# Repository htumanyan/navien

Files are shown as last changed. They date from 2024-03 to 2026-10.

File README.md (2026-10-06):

# Navien ESPHome Integration 🚀🔥

Take control of your **Navien gas water heater** directly from Home
Assistant with this ESPHome module!

No more proprietary lock-ins - this project lets you seamlessly
integrate your Navien system into your smart home setup, giving you
automation superpowers like:

-   📱 Remote start/stop from Home Assistant
-   🔔 "Hot Button" entity that can be triggered from automation
-   ⚡ Climate control for setting the target temperature
-   🛠️ Easy to build, flash, and configure with YAML

## Screenshots 🖼️

Here are some examples of how the integration looks in Home Assistant:

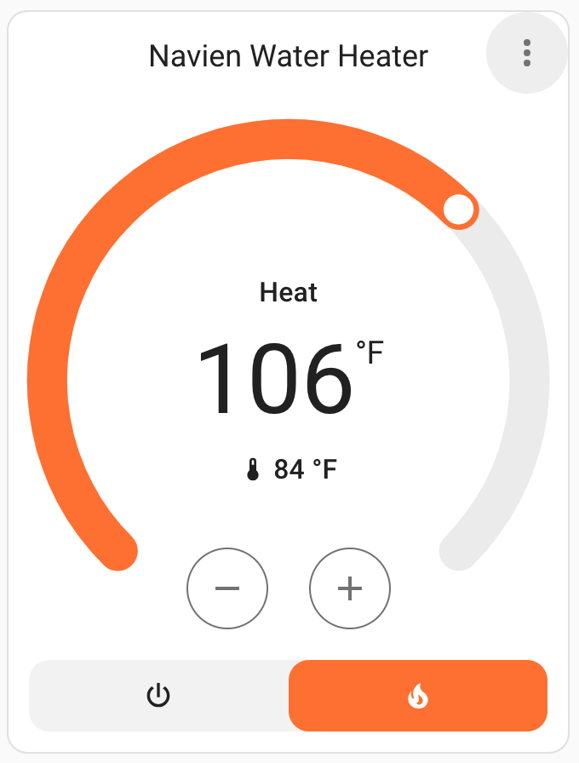
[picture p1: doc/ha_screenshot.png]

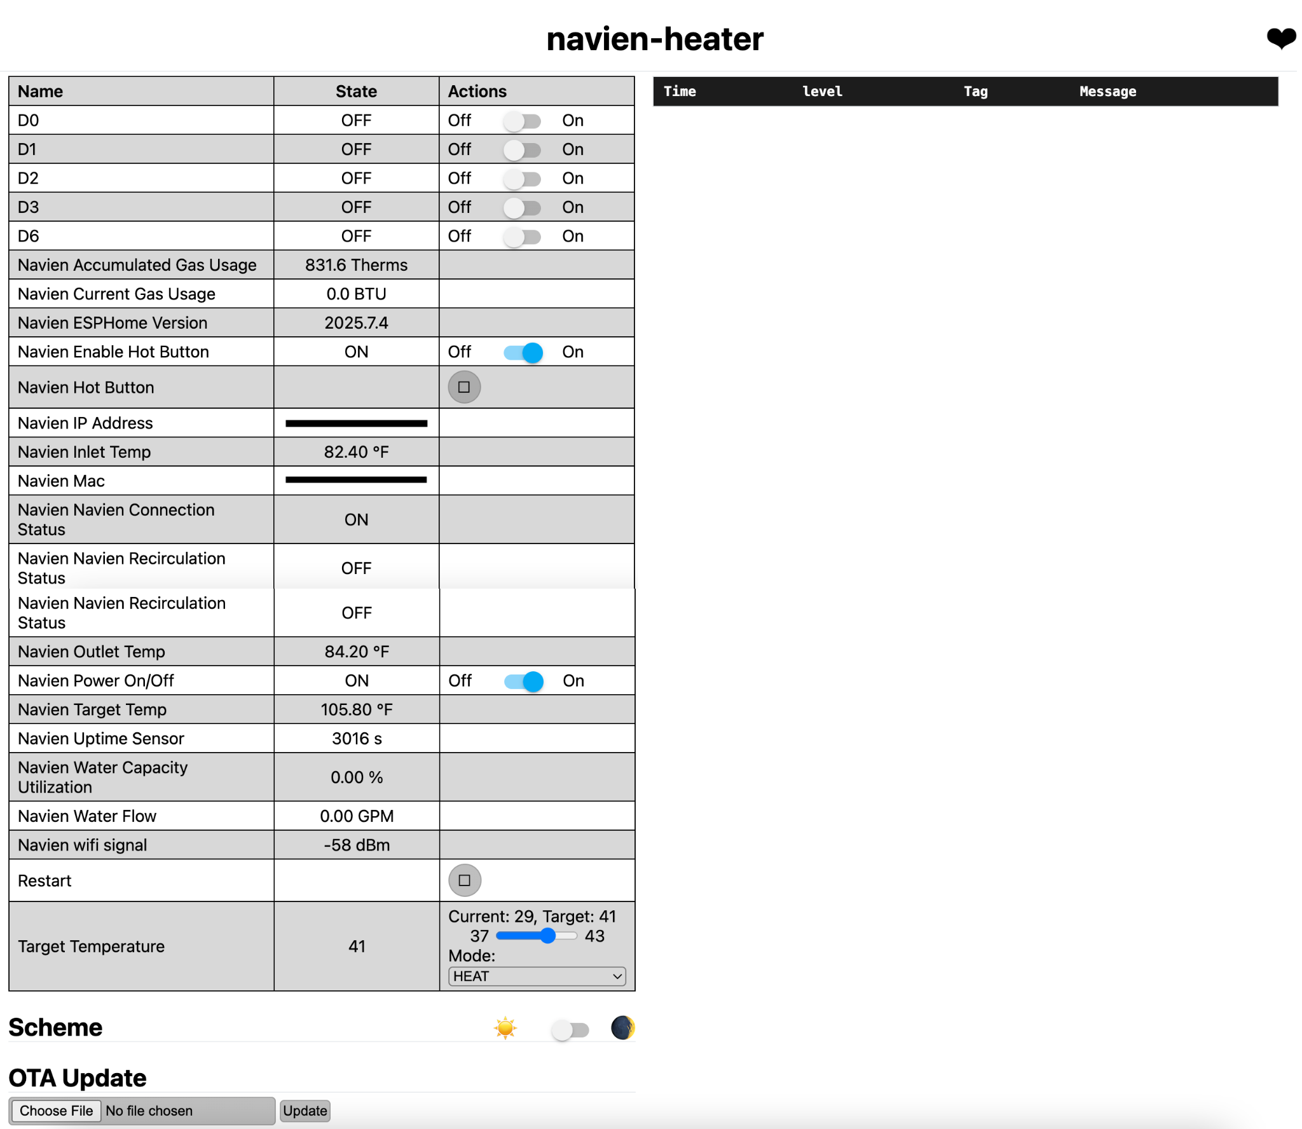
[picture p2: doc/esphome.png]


This project grew out of my work on reverse engineering the native Navien communication protocol to automate my Navien 240a, which it is tested with thoroughly (and works in my home every day). It also incorporates the knowledge from work done by amazing folks in Home Assistant community: [tsquared](https://github.com/tsquared96), [https://github.com/Suva](https://github.com/Suva), [evanjarrett](https://github.com/evanjarrett), David Carson, smurf12345 and many others who contributed in the [community thread](https://community.home-assistant.io/t/navien-esp32-navilink-interface/720567/118)

👉 GitHub Repo: [htumanyan/navien](https://github.com/htumanyan/navien)

------------------------------------------------------------------------

## Getting Started 🛠️

Follow these steps to build and run your own Navien ESPHome integration.

### 1. Clone the Repository

```
git clone https://github.com/htumanyan/navien.git 
cd navien
```

### 2. Install ESPHome

If you don't already have ESPHome installed:

```
pip install esphome
```

For detailed installation instructions, see the [ESPHome Getting Started
guide](https://esphome.io/guides/getting_started_command_line.html).

### 3. Choose Your Configuration

There are five ready-to-use YAML configurations in this repo:

-   **navien-d1-mini.yml** → If you use the D1 Mini board
-   **navien-wrd-hb.yml** → Version for D1 Mini with a hardwired hot button simulator
-   **navien-esphome-atom-lite-esp32.yml** → If you use esp32 Atom Lite board
-   **navien-esphome-lolin-c3-mini.yml** → If you use a LOLIN/WEMOS C3 Mini board
-   **navien-ht-device.yml** → This is for custom esp device that I've designed and plan to open source soon

For ESPHome Dashboard's **Import from URL** workflow, use the LOLIN/WEMOS
C3 Mini package at
`github://htumanyan/navien/esphome/packages/navien-esphome-lolin-c3-mini.yaml@main`.

### 5. Configure Wi-Fi

```
cp secrets.yaml.sample secrets.yaml
```
Edit secrets.yaml - change XXXX to your Wi-Fi network/password and AP SSID network/password in case if it fails to acquire Wi-Fi connection

### 6. Compile and Upload

Compile your firmware:

```
bash esphome compile navien-wrd-hb.yml 
```

**IMPORTANT: ensure that you are running the latest version of esphome, 2025.11.4 or later. Esphome introduced incompatible changes after the version 2025.7.4 that this repo was based off of. Hence it is critical to ensure the latest version of esphome is applied.**

Flash it to your ESP32:

```
bash esphome run navien-wrd-hb.yml
```

### 7. Hardware

#### [Hardware Build Guide — RS485 Adapter](./hardware-guide.md)

Complete guide covering the M5Stack AtomS3 Lite + Atomic RS485 Base build, connector pinouts, wiring, how to enable NaviLink in the Navien installer menu, and common mistakes.

#### [Navien-240 Connector Reference](./doc/240.md)

---

### 8. Importing the Scheduled Recirculation Automation Blueprint

If you have a unit, such as the NPE2 series, that supports scheduled recirculation (meaning it has recirculation modes named something like "Always", "Intelligent", "Weekly", etc), and setting your unit to one of those modes results in the "Navien Recirculation Mode" sensor in Home Assistant reporting "External Scheduled" or "Internal Scheduled", then you can likely use the automation blueprint for scheduling your unit's recirculation times. To do that:

First, you need to create a Schedule entity that will control when circulation is active:

1. In Home Assistant, go to "Settings", "Devices and Services"
2. Click "Add integration"
3. Find "Schedule (helper)" and select it
4. Give the schedule a name like "Navien Recirculation", and set up the schedule (or you can do that part later)
5. Click "Create"

Then, set up the automation:

1. In Home Assistant, go to "Settings", "Automations & scenes", then to the "Blueprints" tab.
2. Click "Import Blueprint" in the lower-right corner
3. Enter Blueprint address: `https://raw.githubusercontent.com/htumanyan/navien/refs/heads/main/navien_schedule_automation_blueprint.yaml`
4. Click "Preview", then "Import blueprint"
5. In the list of blueprints, "Navien Scheduled Recirculation" should now appear. Click it.
6. Fill in all the values per the directions (you might need to create some more helper entities depending on how you want to do things)
7. Click "Save" and give the new automation a name.

### 📖 User Manual for Custom Navien Controller

For detailed instructions on connecting, configuring, and using the custom Navien controller device, see the [User Manual](./doc/user_manual.md). This guide covers hardware setup, wiring, and usage tips specific to the custom controller.

------------------------------------------------------------------------

## [Protocol Details](./doc/README.md) 🔬

If you're interested in how this integration works under the hood, check
out the [doc](./doc/README.md) subfolder.
It contains the **reverse-engineered details of the Navien
protocol**---including message formats, field definitions, and notes
from packet captures.

This section is for developers and contributors who want to:
- Understand the low-level communication between the ESP32 and Navien
heater
- Contribute improvements to the protocol implementation
- Extend support for additional Navien models or features

If you just want to use the integration, you don't need to worry about
this --- but if you love digging into protocols, that's where the magic
happens.

------------------------------------------------------------------------

## Next Steps 🌟

-   Add your device to **Home Assistant** using ESPHome integration.
-   Create **automations and dashboards** to trigger hot water
    recirculation with a tap, schedule, or voice assistant.
-   Share your setup and feedback with the community!

------------------------------------------------------------------------

💡 This project is community-driven. Contributions, pull requests, and
feature ideas are always welcome!

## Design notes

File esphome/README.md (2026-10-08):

# ESPHome Module for Navien
This folder contains a working implementation of Navien tankless water heater protocols in a form of an ESPHome module.

## Supported capabilities
* Reading heater parameters - temperature values, water and gas usage etc.
* Sending commands to start/stop and hot button
* Setting the space-heating (supply water) setpoint on combi / boiler units (verified on NCB-H) - see below

## Space-heating setpoint (combi / boiler units)

`send_sh_set_temp_cmd(deg_c)` sets the SH supply setpoint. There is no dedicated
platform yet; a template number works, and showing the unit's *reported* value
(not the last value typed) makes a rejected command visible:

```yaml
number:
  - platform: template
    name: "SH Setpoint"
    unit_of_measurement: "°F"
    device_class: temperature
    min_value: 104      # NCB-H SH range; the unit clamps anything outside it
    max_value: 180
    step: 1
    mode: box
    update_interval: 2s
    lambda: |-
      if (!id(navien_main).has_data()) return NAN;
      return id(navien_main).get_sh_set_temp_c() * 9.0f / 5.0f + 32.0f;
    set_action:
      - lambda: |-
          id(navien_main).send_sh_set_temp_cmd((x - 32.0f) * 5.0f / 9.0f);
```

The unit works in 0.5 °C steps (0.9 °F), so values round: 158 °F lands as 158.9.

## Requirements

The build script requires Python 3.11+ and one of:
- [uv](https://docs.astral.sh/uv/) (recommended)
- esphome installed via pip

## Usage

### Interactive build script (recommended)

```bash
cd esphome
uv run python build.py
```

The script will:
1. Prompt for WiFi credentials on first run (saved to `secrets.yaml`)
2. Let you select a hardware configuration
3. Choose an action (compile, upload, run, logs)
4. Copy firmware to `../build/` on successful compile

Your choices are persisted, so subsequent runs use your previous selections as defaults.

### Available configurations

| Config | Hardware |
|---|---|
| navien.yml | D1 Mini (ESP8266) - main config |
| navien-d1-mini.yml | D1 Mini variant |
| navien-esphome-atom-lite-esp32.yml | ESP32 Atom Lite |
| navien-esphome-atoms3-lite-tail485-esp32.yml | M5Stack AtomS3-Lite + Tail485 |
| navien-esphome-waveshare-esp32s3-rs485can.yml | Waveshare ESP32-S3-RS485-CAN |
| navien-ht-device.yml | Custom HT device |
| navien-wrd-hb.yml | D1 Mini with hardwired hot button |

### Manual build

If you prefer to run esphome directly:

```bash
cd esphome
cp secrets.yaml.sample secrets.yaml
# Edit secrets.yaml with your WiFi credentials

esphome compile navien.yml
esphome run navien.yml
```

### Alternative installation methods

**Using pip:**
```bash
pip install esphome
esphome compile navien.yml
```

**Using Docker:**
```bash
docker run --rm -v "${PWD}":/config esphome/esphome compile navien.yml
```

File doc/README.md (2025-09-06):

# Navien Tankless Heather Protocol

This repository captures reverse engineered description of the low level details on communication between Navien tankless water heaters and the Navilink WiFi lite device.

## High Level Details

Navien supports several types of remote control devices. The older generation, such as NR-21DU and similar connect with two wires that are used to provide power to the remote device and also for the data exchange. Newer and more complex NaviLink devices (NaviLink and NaviLink Lite) connect over RS-485 connector. The documentation refers to power provided over separate pins/wires but my heater did not. I had to connect a separate 12V power supply to the NaviLink lite that was used to capture the traces, analyzed here.

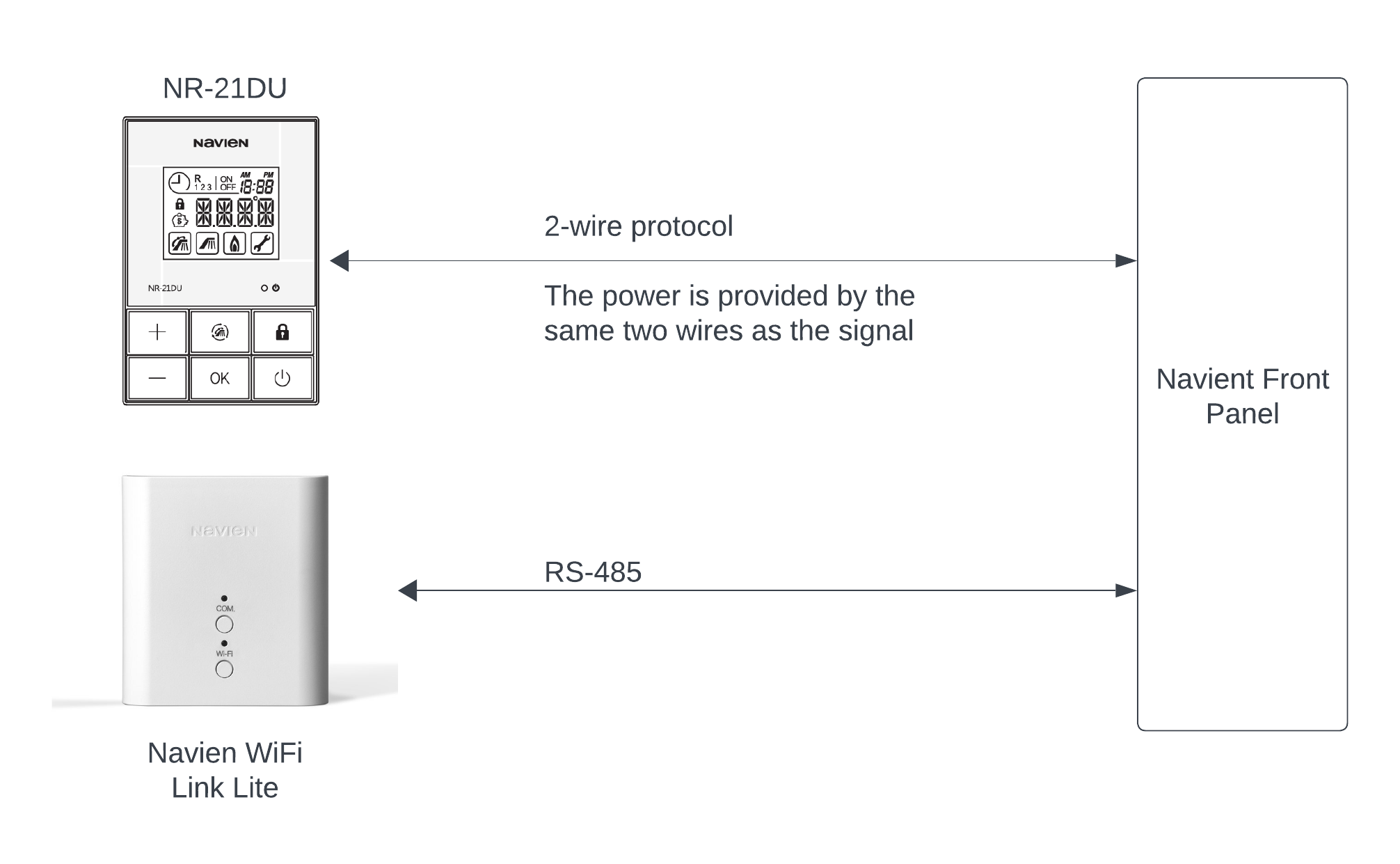
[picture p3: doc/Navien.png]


## Protocols
### [RS485 Connection](rs485.md)

 <!-- ### [2-Wire Connection](/doc/2-wire.md)-->

## Hardware/Firmware Exploration
## [Navien Wifi Link Lite](navien_wifi_debug.md)

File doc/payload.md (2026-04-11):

# Packet Types
The Navien protocol has two primary types of packets:

* Reporting Packets: These are sent from the heater to the consumer device. They contain various pieces of information, including heater status, temperature readings, flow rate (GPM), gas usage values, and other operational data.

* Control Packets: These are sent from the controller device to the heater. They are responsible for issuing commands, such as adjusting temperature settings, activating specific features, or controlling the heater's operation.

## Reporting Packets
Reporting packets are sent by Navien water heaters to indicate the status of the device. There are two kinds of reporting packets:

* Water - shows temperature values and the water flow
* Gas - temperatue values and gas usage.

Interestingly, the temperature values in gas and water packets, while often similar, are not always identical. It is likely that these values represent temperatures measured at closely located points within the system.

This distinction suggests that the gas and water temperature readings serve specific purposes, reflecting measurements taken at different but closely connected stages of the heating process.

Gas and water status segments are selected by destination/service routing in header byte 0x03 (`dst`), not by a standalone packet-kind byte.

For full source/destination/direction routing details, see [Protocol Data Flow](./protocol_data_flow.md).

```
+---------------------------------------------------
| F7 | Unknown Byte | Src | Dst | Direction | ....
+---------------------------------------------------

F7 - the fixed marker of a beginning of the packet

Unknown byte** - observed as 0x05, likely protocol/version marker

Src** - source node ID (for example `0x50` main status source, `0x0F` local controller)

Dst** - destination/service routing byte (`0x50` water status path, `0x0F` gas status path)

Direction** - parser treats `0x90` as status path and `0x10` as control path
```

### Sample Water Header

```
+---------------------------------------------------
| F7 | 0x05 | 0x50 | 0x50 | 0x90 | ....
+---------------------------------------------------
```

### Sample Gas Header

```
+---------------------------------------------------
| F7 | 0x05 | 0x50 | 0x0F | 0x90 | ....
+---------------------------------------------------
```

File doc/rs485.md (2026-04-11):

# The protocol over RS485 line

## Hardware Level

Analyzing the signal with an oscilloscope shown +12v and -12v pulses, which hinted that the signal may be regular RS485. That was confirmed later when connected Saleae logic analyzer. More detailed look into the timing of logic signals suggested the following parameters of the signal encoding:

* Speed 19200 bod
* 8 bit data frames
* 1 stop bit
* No parity

This was later confirmed in reverse engineering the firmware with Ghidra.

## Protocol

THe protocol is pretty simple in that there is no time coordination between requests and responses. Rather both sides, the remote control device and the heater just send packates over "their direction" of rs485. In other words, the communication is full duplex with two sides sending packets as they are ready.

## Packet Format

All packets, in both directions have a common overall format consisting of header, data part and a control sum.

Packets always start with a byte value 0xF7, which serves as a marker of starting the frame (also confirmed in reversed code).

| &nbsp; &nbsp; Header &nbsp; &nbsp; | &nbsp; &nbsp; &nbsp; &nbsp; &nbsp; &nbsp; &nbsp; &nbsp; Data &nbsp; &nbsp; &nbsp;  &nbsp; &nbsp;&nbsp;&nbsp; &nbsp; &nbsp; &nbsp; | &nbsp; &nbsp;  Checksum &nbsp; &nbsp;  |
|---|---|---|

#### Example

| | |
|---|---|
|Header|F7 05 50 50 90 22 | 
|Data | 42 00 00 25 49 5C 5B 53 00 00 00 00 00 00 88 C2 00 20 02 00 00 00 21 03 99 08 00 02 00 00 00 00 00 00 |
|Checksum| 87 |

### Header

Header fields are now better understood and mapped to current parser behavior.
These protocol flow learnings were refined during cascade troubleshooting and debug work with @matthewhadley.
For detailed flow semantics, see [Protocol Data Flow](./protocol_data_flow.md).

The table below shows known header field meanings:

| Offset | Purpose / Meaning |
|---|---|
| 0x00 | 0xF7 - fixed value. Marks the start of frame | 
| 0x01 | Observed to be always 0x05. However in the code there are references to 0x05 and 0x01 as well a a check for value to be in [1..9] range. |
| 0x02 | Source ID (`src`). Key values include: `0x01` (peer/panel handshake path), `0x0F` (local controller outbound sender), and `0x50..0x5F` (cascade unit range). Navien uses `0x50` and above for cascaded units (second, third, ... up to 15 units). |
| 0x03 | Destination ID (`dst`). Common observed values include `0x01`, `0x0F`, and `0x50`. Status parsing routes water/gas only for `0x50` and `0x0F`. |
| 0x04 | Direction byte. Known values used by parser gates are `0x10` and `0x90`. |
| 0x05 | Data length in bytes = packet length - header length - 1 byte for the checksum |

#### Example
| | |
|---|---|
|0xF7| Packet start marker |
|0x05| Unknown, always 0x05
|0x50| Source ID (`src`) |
|0x50| Destination ID (`dst`) |
|0x90| Direction |
|0x22| Length, 34 bytes
|42 00 00 25 14 5F 4C 4C 00 00 00 00 00 00 88 C2 00 20 02 00 00 00 21 03 9A 08 00 02 00 00 00 00 00 00| Data| 
|0xD8| Checksum

### [Protocol Data Flow](./protocol_data_flow.md)

### [Data Payload](/doc/payload.md)

### [Checksum Algorithm](/doc/checksum.md)

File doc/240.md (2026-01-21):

# Navien-240 hardware (240A / 240A2)

## Overview

This page is based on my research and experimentation, as well as contributions from the Home Assistant community, about the Navien-240 models (240A and 240A2) electronic internals.

## Front Display

### 240A

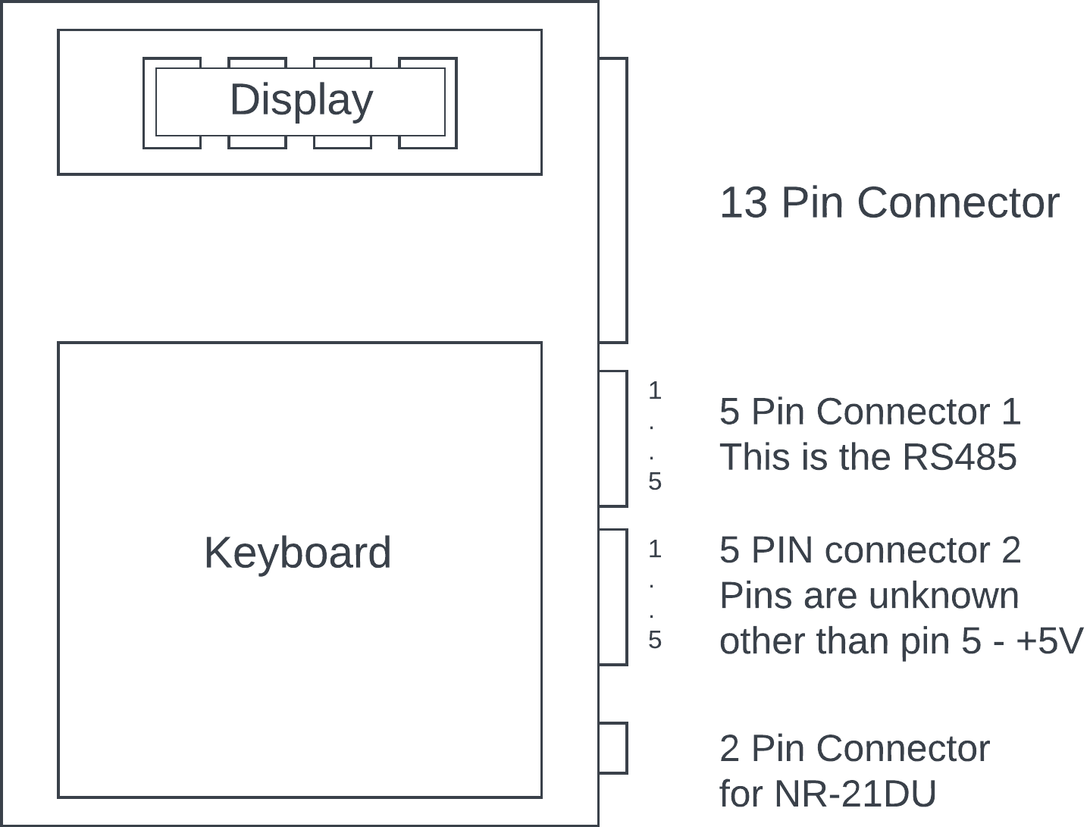
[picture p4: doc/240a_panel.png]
240A front panel


### 240A2

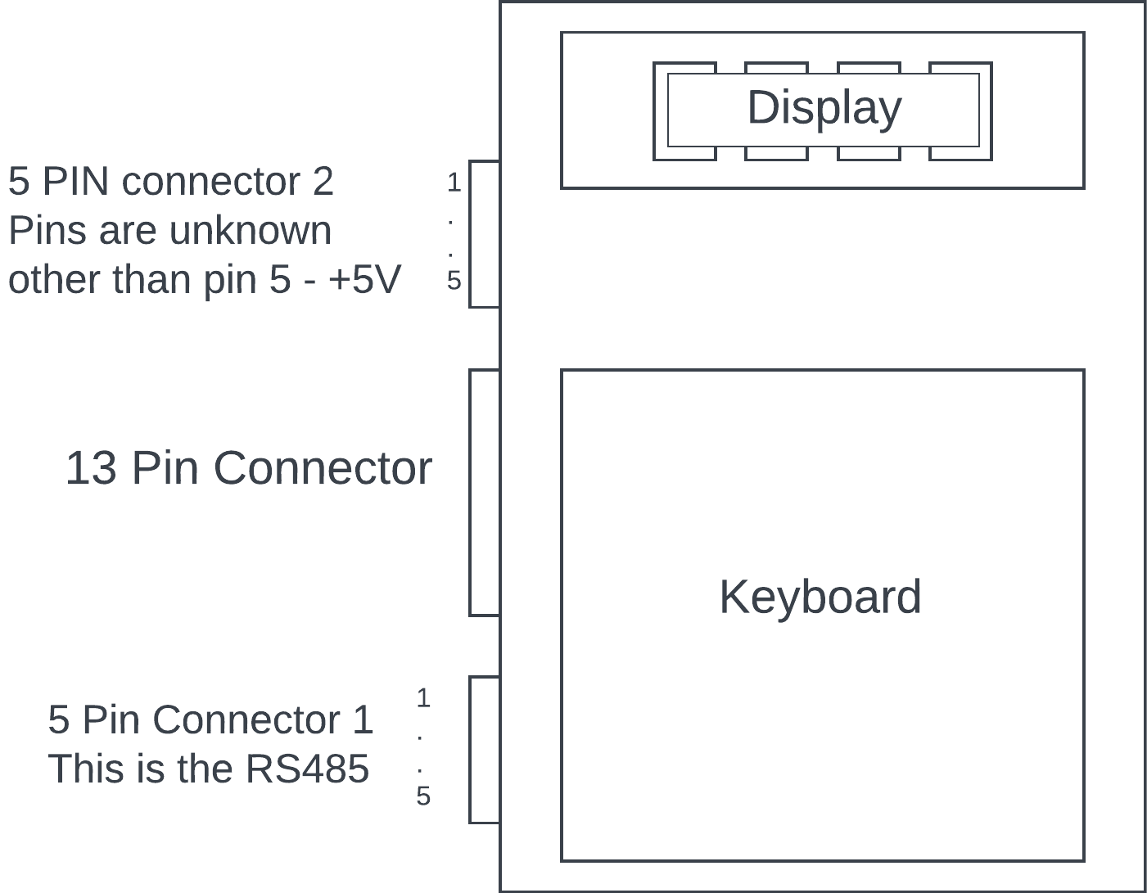
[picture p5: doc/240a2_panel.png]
240A2 front panel


## 5 Pin Connector 1 - RS-485 connection

| Pin | Purpose  |
|---|---|
| 1 | Unknown. Some reports indicate +13V in Navien-240A version |
| 2 | RS-485 B- |
| 3 | RS-485 A+ |
| 4 | Unknown |
| 5 | GND |

## 5 Pin Connector 2 - Largely Unknown, but has +5V

| Pin | Purpose  |
|---|---|
| 1 | Unknown |
| 2 | Unknown |
| 3 | Unknown |
| 4 | Unknown |
| 5 | +5V |

I've used the +5V to supply power to esp-8266, appears to have enough for it.

## 8 Pin RJ45 Connector (the one that comes with a NaviLink Lite)

If you want to use the cable that comes with the NaviLink Lite to connect via an RJ45 breakout board, here's the mapping to the 5 Pin connector 1:

| RJ45 Pin | Equiv. on connector 1 | Purpose |
|---|---|---|
| 1, 2 | 1 | +13V? |
| 4 | 3 | RS-485 A+ |
| 5 | 2 | RS-485 B- |
| 7, 8 | 5 | GND |

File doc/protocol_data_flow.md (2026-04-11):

# Navien Protocol Data Flow (RS-485)

This document summarizes observed and inferred data-flow rules for Navien packet headers.

## Header Field Semantics

### Source (`src`)

| Field | Value | Role / Semantics | Where It Is Used |
|---|---:|---|---|
| `src` | `0x01` | Peer/panel endpoint used by observed handshake/control-init traffic | Header comments and observed traffic |
| `src` | `0x0F` | Local gateway/controller ID (outbound sender) | Outbound builders set `src=0x0F` |
| `src` | `0x50` | Primary boiler telemetry source | Main parser status path, CRC seed `0x4B` branch |
| `src` | `0x50..0x5F` | Cascade unit source range (`0x50` base + unit index) | `Navien::on_water/on_gas` filter uses `PACKET_SRC_STATUS + src_`; Navien uses `0x50` and above for cascaded units (second, third, ... up to 15 units) |

### Destination (`dst`)

| Field | Value | Role / Semantics | Where It Is Used |
|---|---:|---|---|
| `dst` | `0x01` | Handshake target peer | Handshake builder sets `dst=0x01` |
| `dst` | `0x0F` | Local gateway/controller destination | Parser accepts for status import |
| `dst` | `0x50` | Main boiler destination path | Parser accepts for status import |
| `dst` | other values | Not imported into water/gas status callbacks | `parse_status_packet()` switches only on `0x50`/`0x0F` |

## Related Fields

| Related Field | Value | Semantics |
|---|---:|---|
| `direction` | `0x10` | Control packet path |
| `direction` | `0x90` | Status packet path |
| parser gate | `direction == 0x90` | Required for status packet parsing |
| status apply gate | `src == 0x50 + src_` | Required per-instance for water/gas state apply |

## Observed / Inferred Flow Patterns

| Src | Dst | Direction | Meaning | Status |
|---:|---:|---:|---|---|
| `0x0F` | `0x01` | `0x10` | Local gateway sends handshake/control-init packet to peer/panel endpoint | Observed |
| `0x01` | `0x0F` (likely) | `0x10` | Peer/panel-origin packet path | Inferred from comments and observed traffic |
| `0x0F` | `0x50` | `0x10` | Local gateway sends control requests toward main boiler node | Observed (command templates/builders) |
| `0x50` | `0x0F` | `0x10` or `0x90` | Main boiler telemetry/status accepted by parser for local import | Observed |
| `0x50` | `0x50` | `0x10` or `0x90` | Main-node loop/forwarded status path still accepted by parser | Observed |
| `0x50..0x5F` | `0x50` or `0x0F` | `0x90` | Cascade unit source range; per-instance apply uses `src-0x50` mapping | Inferred from instance filtering |

## Validation Rules

| Validation Rule | Semantics |
|---|---|
| `direction == 0x90` | Status CRC/parse path |
| `direction == 0x10 and src == 0x0F` | Control CRC/parse path |
| `direction == 0x90 and src == 0x50` | Status CRC uses seed `0x4B` |
| `direction == 0x90 and src != 0x50` | Status CRC uses seed `0x62` |
| `direction == 0x90 and dst in {0x50, 0x0F}` | Status segment routed to water/gas callbacks |
| `src == 0x50 + src_` (in Navien instance) | Water/gas state applied for matching unit only |

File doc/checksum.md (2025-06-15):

#  Checksum Algorithm

## Overview

The checksum algorithm initially appeared to be similar to CRC. After trying all known CRC values and implementations and failing to find a match to observed network traces I've pivoted to the hard way of reversing the assembly code and coding the algorithm in C/C++ based on inferred knowledge.

## Data Input
Notice that the checksum is generated across the whole packet, which includes the header and the data payload. Essentially, the validation code removes the very last byte that carries the checksum, computes the checksum on the remaining buffer and then compares the computation result to the removed byte. Similarly, the sender computes the checksum over the whole message that includes the header and data and then appends the computed checksum byte at the end.

## Seed Values

Just like CRC, the Navien checksum protocol employs a seed value. There are two known seed values that are selected in the code based on the value at offset 2 in the header (likely the protocol version). If the version value is 0x50 the seed is 0x4b. Otherwise it is 0x62. Notice that I never observed the 0x4b value in real world traces, so for all practical purposes the value needs to be 0x4b

## Algorithm

```
byte likely_crc_calc(const byte * buffer,uint len,ushort seed){
  ushort result;

  if (len < 2) {
    result = 0x00;
  }
  else {
    result = 0xff;

    for (uint i = 0; i < len; i++){
      result = result << 1;

      if (result > 0xff){
        result = (result & 0xff) ^ seed;
      }

      // this is important!!
      // the checksum is calculated
      // based on the lower byte, i.e.
      // only the lower byte is XOR-ed
      result = ((byte)result) ^ (ushort)buffer[i];
    }

  }

  return result;
}
```

### Working Code
There is a [working C/C++ code](/src/checksum.cpp) with test vectors derived from line captures. It can be compiled with GCC as follows:

```
gcc -g crc.cpp
```

It will produce the default a.out file in the current working directory that will run the tests if executed.

[Link to the working code with test cases](/src/checksum.cpp)

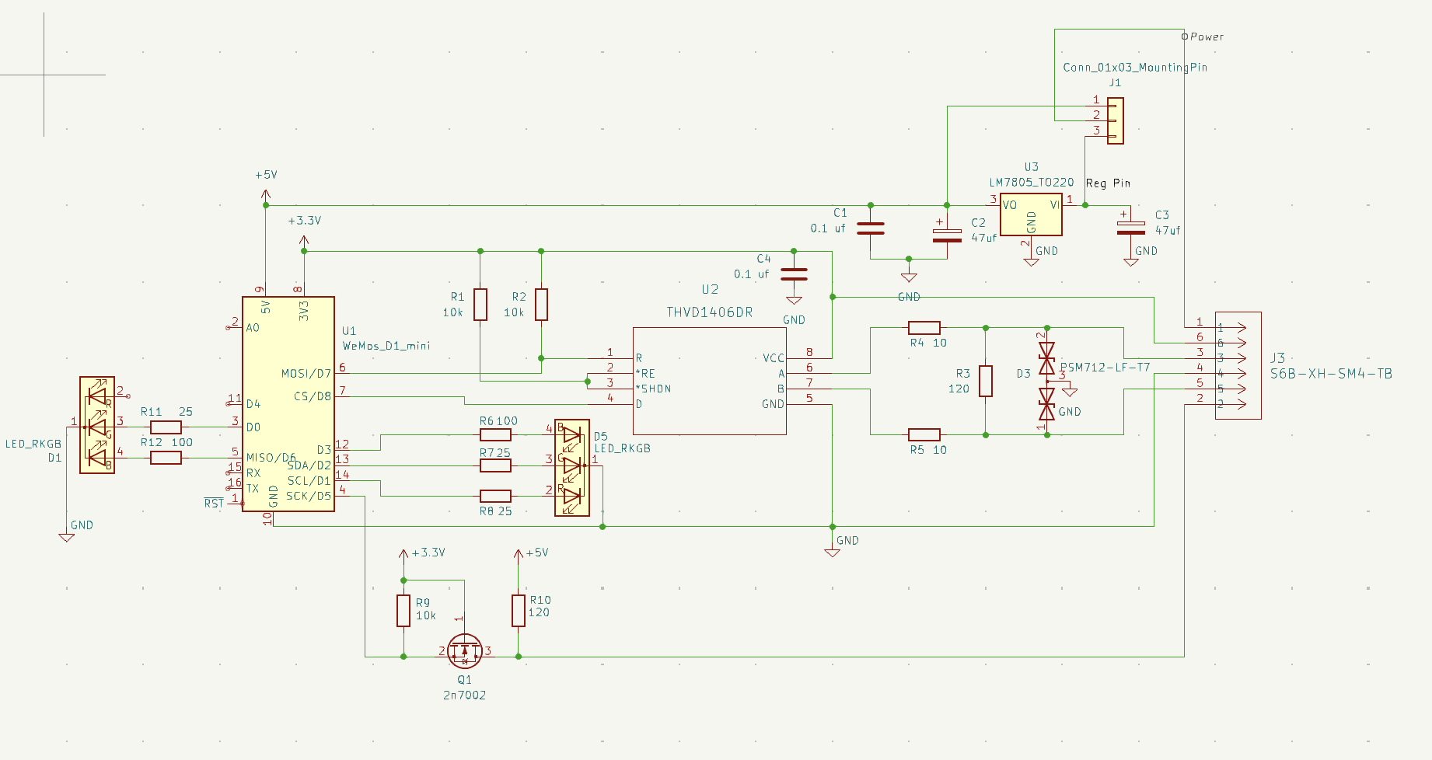
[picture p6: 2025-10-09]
hardware/Schematic.png

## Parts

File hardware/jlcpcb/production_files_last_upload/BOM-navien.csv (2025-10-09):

Comment | Designator | Footprint | LCSC | Quantity
100 | R12,R6 | R_0805_2012Metric_Pad1.20x1.40mm_HandSolder | C17408 | 2
10k | R1,R2,R9 | R_0805_2012Metric_Pad1.20x1.40mm_HandSolder | C17414 | 3
10 | R4,R5 | R_0805_2012Metric_Pad1.20x1.40mm_HandSolder | C17415 | 2
120 | R10,R3 | R_0805_2012Metric_Pad1.20x1.40mm_HandSolder | C17437 | 2
25 | R11,R7,R8 | R_0805_2012Metric_Pad1.20x1.40mm_HandSolder | C17634 | 3
S6B-XH-SM4-TB | J3 | CONN_S6B-XH-SM4-TB_JST | C191914 | 1
0.1 uf | C1,C4 | C_0805_2012Metric_Pad1.18x1.45mm_HandSolder | C28233 | 2
PSM712-LF-T7 | D3 | SOT-23 | C32677 | 1
THVD1406DR | U2 | SOIC_D0008A_TEX | C5215918 | 1
47uf | C2,C3 | C_0805_2012Metric_Pad1.18x1.45mm_HandSolder | C53134 | 2
LED_RKGB | D1,D5 | LED-ARRAY-SMD_4P-L1.6-W1.5-BL-FD-WITH-PIPE-2 | C601684 | 2
2n7002 | Q1 | SOT-23 | C8545 | 1

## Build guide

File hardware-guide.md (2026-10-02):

# Hardware Build Guide — RS485 Adapter for Navien

This guide summarizes everything you need to build a working RS485 adapter for your Navien tankless water heater, based on hundreds of posts from the [Home Assistant community thread](https://community.home-assistant.io/t/navien-esp32-navilink-interface/720567). It covers the Navien-side connector, four proven hardware options, wiring tables, and the common mistakes people make.

For full installation and parameter details, refer to the [Navien NPE-A/S Installation Manual](https://www.navieninc.com/downloads/npe-a-s-manuals-installation-manual-en).

---

## Before You Start: Enable NaviLink in the Installer Menu

**This is the single most common reason for a completely silent RS485 bus.** If the NaviLink communication mode is not enabled, your Navien unit sends no RS485 traffic at all, regardless of your hardware.

Access the installer menu as follows:

1. From the home screen, press and hold **Menu** and **↩ (back arrow)** simultaneously for 3 seconds. The service installer menu will appear.
2. Choose **option 1** to enter the installer menu and press **OK**.
3. Enter the default password **1234** using the up/down arrow buttons, then press **OK**.
4. Select **option 3 — Application Settings**, press **OK**.
5. Select **option 1 — NaviLink**, press **OK**.
6. Select **option 1 — NaviLink Connection**, press **OK**. Read the info screen and press **OK** again.
7. Move the cursor to **Enable** under NaviLink Connection and press **OK**.
8. Press **↩** repeatedly to exit all menu screens. The unit will reboot and purge the lines. Your ESP should then begin reporting data.

> **Note:** Units manufactured before approximately 2016 do not support NaviLink and cannot be used with this project.

---

## Physical Connector on the Navien Unit

The RS485 data connector is a **JST XH (2.54 mm pitch), 5-pin** connector located on the front display panel of the unit — the same port where the NaviLink Lite cable plugs in.

To access it:
1. Power off the Navien unit and unplug it from the wall.
2. Remove the front panel (typically two screws at the top, two at the bottom).
3. The RS485 connector is the 5-pin JST XH jack on the front display board.

| 240A front panel | 240A2 front panel |
|:---:|:---:|
| **Navien 240A** — RS485 connector is left of the back-arrow button | **Navien 240A2** — same connectors, mirrored position |

| 5-pin JST XH connector on the Navien 240A front panel | 5-pin JST XH connector on the Navien 240A2 front panel |
|:---:|:---:|
| 5-pin JST XH connector on the **Navien 240A** front panel | 5-pin JST XH connector on the **Navien 240A2** front panel (green PCB visible to the right of the display) |

### 5-Pin Connector 1 — RS485 Data

| Pin | Purpose |
|-----|---|
| 1 | ~+13 V (Navien 240A) |
| 2 | RS-485 B− |
| 3 | RS-485 A+ |
| 4 | Unknown / unused |
| 5 | GND |

### Mating Connector — JST XH vs XHB

The Navien uses a **JST XH** socket (2.54 mm pitch). You need a mating plug to connect your cable. There are two variants:

| | JST XH | JST XHB |
|---|---|---|
| Locking clip | No | Yes — a small plastic tab that clicks into place |
| Fits Navien socket | Yes | Yes |

Both variants are electrically identical and physically compatible with the Navien socket. The XHB locking clip is a convenience feature — the plain XH plug holds securely enough for a permanent install.

**Where to buy:**
- [Amazon — ACEIRMC 10-pair 5-pin JST **XH** connectors (male + female)](https://www.amazon.com/ACEIRMC-10Pairs-Connector-Connectors-Compatible/dp/B0D3LZHSTP)
- [AliExpress — JST **XHB** 5-pin connector set (locking)](https://www.aliexpress.us/item/3256806321864401.html)

| JST XH 5-pin connector | JST XHB 5-pin connector |
|:---:|:---:|
| JST XH — no locking clip | JST XHB — locking clip |

### Hot Button Requirement

The **hot button** feature (triggering instant hot water recirculation) requires two things: the Navien hot button kit must be installed on the main board, and the unit must be configured to **External HotButton** recirculation mode. If the mode is not set correctly, the Hot Button entity in Home Assistant will do nothing when pressed.

Whether the hardware is pre-installed depends on your model:

- **NPE-240A2** — the hot button kit comes **pre-installed**. No additional steps needed.
- **Other models (e.g. NPE-240A, NPE-210S)** — the hot button kit is **not included**. You must either purchase and install the official Navien hot button kit, or make the DIY bypass described below.

#### DIY Hot Button Bypass (13-pin JST XH connector)

The main board has an empty 13-pin JST XH socket where the hot button board plugs in. You can simulate the hot button kit by plugging a JST XHP-13 connector into that socket with two pins shorted together, and a wire on the +5 V pin that your ESP32 can pull low to trigger a hot button press.

> The 13-pin connector is **JST XH** (plain, no locking clip) — not XHB.

| 13-pin hot button bypass on the Navien main board |
|:---:|
| Annotated 13-pin connector. The embedded labels describe triggering a physical hot button press via a relay. The pin labelled "+5V" is a digital input that is pulled high — to trigger the hot button, pull it to 0 V. If you only want RS485-based virtual hot button (no relay), you need just 4 pins total: the two pins shorted together, and the 10 KΩ resistor |

#### Hot Button DIP Switches

The hot button controller board has a 4-position DIP switch (SW1) that controls its behavior:

| DIP SW | OFF | ON |
|---|-----|----|
| 1 | Enable the HotButton | Disable the HotButton |
| 2 | Enable the energy saver function | Disable the energy saver function |
| 3 | Reserved | Reserved |
| 4 | Reserved | Reserved |

| HotButton DIP switch diagram |
|:---:|
| SW1 DIP switch on the hot button controller board |

#### Temperature Sensor and SENSOR I Contacts

The hot button controller has a **SENSOR I** input for an optional recirculation return-line temperature sensor. By default, two metal contacts on SENSOR I are bridged by a metal plate — this is the no-sensor configuration and works without modification.

If you want to connect a temperature sensor, remove the metal plate before connecting the sensor. **Do not leave the plate installed while connecting a sensor, as this will short the sensor input.**

For most users: leave the metal plate in place and skip the temperature sensor entirely.

#### Fixture Distance (Parameter 16)

When no temperature sensor is connected (the default), the unit uses **Parameter 16** (fixture distance) to determine when to stop recirculating. The default value is **30 ft**. Adjust this parameter to match the approximate distance from the water heater to the furthest fixture if your setup differs significantly.

### RS485 Signal Levels

The Navien RS485 bus operates at standard RS485 differential levels (±12 V swing). Your RS485 transceiver IC handles the conversion to 3.3 V/5 V TTL logic for the ESP — **no separate level shifter is needed** on the RS485 data lines.

**UART settings for all configurations:**
- Baud rate: **19200**
- Data bits: 8
- Stop bits: 1
- Parity: None

---

## Hardware

The recommended build is the **M5Stack AtomS3 Lite + Atomic RS485 Base**. The base snaps onto the bottom of the AtomS3 Lite, accepts 12 V input directly from the Navien connector, and provides regulated power to the AtomS3 Lite. No breadboard or soldering required for the ESP side.

**Parts:**
- M5Stack AtomS3 Lite (ESP32-S3)
- [M5Stack Atomic RS485 Base](https://docs.m5stack.com/en/atom/Atomic%20RS485%20Base)
- JST XHP-5 (plain) or XHB (locking) 5-pin connector + wire, or pre-made cable

> **Termination resistor:** There is conflicting information about whether the Atomic RS485 Base includes an integrated 120 Ω termination resistor. The [latest schematics](https://docs.m5stack.com/en/atom/Atomic%20RS485%20Base) suggest it does; however, an [M5Stack example project](https://docs.m5stack.com/en/arduino/projects/atomic/atomic_rs485_232_base) calls for adding an external one. Other M5Stack RS485 products also ship with a loose through-hole resistor in the package — if yours does, use it across the A and B terminals. Do not add an external resistor if the base already has one integrated, as two resistors in parallel would drop the effective termination resistance below the correct 120 Ω. A unit ordered in June 2026 worked correctly without adding an external resistor.

| 120 Ω resistor across A and B terminals on the Atomic RS485 Base |
|:---:|
| 120 Ω resistor across the A and B terminals (highlighted) |

| M5Stack AtomS3 Lite + Atomic RS485 Base |
|:---:|
| Very nicely made custom cable with heat shrink, wire loom, and ferrules. Uses JST-XH connectors. |

**Wiring:**

| Atomic RS485 Base Terminal | Navien Connector 1 |
|---|---|
| B | Pin 2 (RS-485 B−) |
| A | Pin 3 (RS-485 A+) |
| 12V | Pin 1 (~+13 V) |
| GND | Pin 5 (GND) |

> Powering the base from the Navien's Pin 1 (+13 V) works reliably. The Atomic RS485 Base accepts 12–32 V input and provides regulated power to the AtomS3 Lite.

**UART pins (AtomS3 Lite):**

| Signal | GPIO |
|---|---|
| TX | GPIO2 |
| RX | GPIO1 |

**ESPHome YAML:** [`navien-esphome-atoms3-lite-rs485base-esp32.yaml`](esphome/packages/navien-esphome-atoms3-lite-rs485base-esp32.yaml)

### ESPHome Configuration

The easiest way to get started is to import the board config directly in the ESPHome dashboard using the **Import from URL** option with this URL:

```
github://htumanyan/esphome-navien/esphome/packages/navien-esphome-atoms3-lite-rs485base-esp32.yaml@main
```

This generates a minimal local config that pulls the full component definition from GitHub at build time. You only need to add your wifi credentials:

```yaml
substitutions:
  device_name: navien-abc123
  friendly_name: Navien abc123

packages:
  navien_board:
    url: https://github.com/htumanyan/esphome-navien
    ref: main
    files: [esphome/packages/navien-esphome-atoms3-lite-rs485base-esp32.yaml]
    refresh: 1d

esphome:
  name: ${device_name}
  name_add_mac_suffix: false
  friendly_name: ${friendly_name}

api:
  encryption:
    key: <your generated key>

wifi:
  ssid: !secret wifi_ssid
  password: !secret wifi_password
  ap:
    ssid: ${device_name} AP
    password: !secret ap_password
```

Updates to the shared component config are picked up automatically on the next compile — no need to re-import.

---

## Common Mistakes

1. **NaviLink not enabled in the installer menu.** The most common cause of a completely silent bus. Follow the steps at the top of this guide.

2. **RS485 A/B wires reversed.** If you get garbage data or silence, swap A and B.

3. **Termination resistor.** See the note in the Hardware section above — whether to add one depends on your specific unit.

4. **Wrong on/off byte values.** The NPE-240A and NPE-240A2 use different byte values for power state. Make sure you're using the right config file for your unit.

5. **ESPHome version.** Version 2025.7.4 introduced breaking changes. Use **2025.11.4 or later**.

---

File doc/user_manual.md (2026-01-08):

# Legal Notices

**READ THIS FIRST.** This custom controller (“Device”) is an aftermarket, third-party product that is **not manufactured, endorsed, certified, or supported by Navien**. Use of this Device may affect equipment operation, safety protections, warranty coverage, and regulatory compliance.

By installing, powering, or using the Device, you acknowledge and agree that:

- **Use is entirely at your own risk.**
- The Device is provided **“AS IS” and “AS AVAILABLE,”** without warranties of any kind, express or implied, including (without limitation) implied warranties of merchantability, fitness for a particular purpose, non-infringement, or that the Device will be error-free or uninterrupted.
- **No liability is assumed** by the developer, designer, seller, or distributor of the Device for any direct, indirect, incidental, special, consequential, exemplary, or punitive damages, including (without limitation) property damage, personal injury, loss of hot water, loss of heating, loss of data, loss of profits, or business interruption, arising out of or related to installation or use of the Device—even if advised of the possibility of such damages.
- You are solely responsible for **safe installation**, verifying compatibility, following all applicable **electrical codes**, and complying with all local laws and regulations.
- If you do not accept these terms, **do not install or use** the Device.

---

# User Manual — Navien Water Heater Controller (Custom Hardware)

## Table of Contents
1. Precautions  
2. Connections  
3. Powering the Unit  
4. LED Indicators  
5. Wi-Fi Connection  
6. Troubleshooting  

---

## Precautions

- **Never connect or disconnect the controller when the Navien unit is powered on.**  
  Always turn off the Navien unit and **unplug the power cord from the receptacle** before making or changing any connections.

- Before making any connections, ensure that the **power is turned off to all units** involved (Navien unit, any external power supply, and any nearby control equipment).

- Handle cables gently. Avoid bending, pinching, or pulling wires under tension.

---

## Connections

Your controller has **two connectors**:

### A) Micro-USB connector (side)
Used for:
- **Firmware upgrades**
- **Powering the controller**, if your Navien unit does not provide power (see **Powering the Unit**)

### B) 6-pin connector (Navien cable)
This connector receives the cable that connects the controller to the Navien unit. 

---

## Powering the Unit

### Option 1 (Universal): USB 5V power
The simplest way to power the unit is using a **standard 5V USB charger**, such as a typical phone power brick.

Steps:
1. Connect Micro-USB to the controller.
2. Plug the charger into AC power.
3. Confirm the controller powers on (see **LED Indicators**).

### Option 2: Power from the Navien unit (Navien 240 models)
**Your Navien 240 cable kit includes an additional small 5-pin connector with only one red wire.** This connector is used to draw **+5V power** from Navien 240 models (including **240A and 240A2**) and power the controller without an external USB charger.

Navien 240 models provide +5V power on the **second 5-pin jack on the front panel** (as shown in the photo). The controller can be powered from that jack using the single-red-wire connector.

To power the controller from a Navien 240 model:
1. Turn the Navien unit **OFF** and **unplug** it from the wall.
2. Locate the **second 5-pin jack** on the front panel.
3. Insert the **single-red-wire 5-pin connector** into that jack.  
   **Important:** this jack is **not keyed**. The connector must be inserted with the **red wire positioned at the bottom** (as shown in the photo).
4. Reconnect the main controller cable as usual.
5. Plug the Navien unit back in and power it on.

| Navien 240A front panel | Navien 240A2 front panel |
|:---:|:---:|
| **Navien 240A front panel** | **Navien 240A2 front panel** |

---

## Installation and Wiring

Steps:
1. Unpackage the controller and cable.
2. Plug the cable into the controller’s **6-pin jack**.
3. The connector is **keyed** and fits **only one orientation**.
4. **Do not force it.** If insertion feels wrong, remove it, flip the connector orientation, and try again.
5. Turn off the Navien unit - unplug the power cable from receptacle.
6. Remove the front panel of the Navien unit - it is usually attached by two screws at the top and two at the bottom.
7. Connect the main 5-pin connector (it has multiple wires going in it, as opposed to the second 5-pin connector that has just one red wire) to the 5-pin slot on the front display.
8. If your Navien unit is 240A and you don't have the Navien hot button kit installed, then insert the 13-pin connector into the empty 13-pin slot in the main board of the unit. This is to enable hot button functionality without the actual hot button device. If you have the Navien hot button device, then install it per Navien instructions and ignore this step.
9. Remove the front panel of the Navien unit - it is usually attached by two screws at the top and two at the bottom.
10. Plug in the power receptacle and turn on the Navien unit.

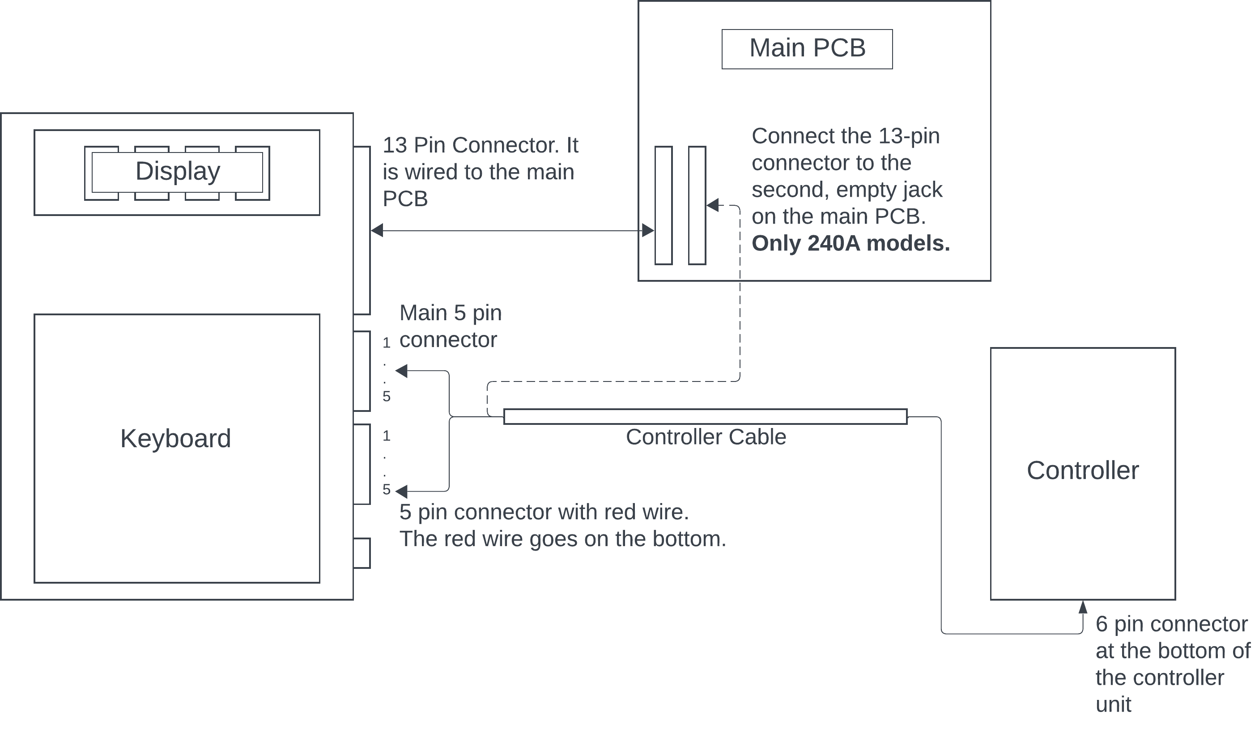
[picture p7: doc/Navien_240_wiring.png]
Navien 240A and 240A2 wiring diagram

**Navien 240A and 240A2 wiring diagram** 

## LED Indicators

There are **two LED indicators**:

### Left LED (Navien connectivity)
This LED can flash **green** or **red** and indicates connectivity to the Navien unit:
- **Green (flashing):** Connected; sending/receiving data  
- **Red (flashing):** Disconnected

✅ The left LED **must be green** for normal controller operation.

### Right LED (Wi-Fi status)
- **Solid Blue:** Connected to Wi-Fi  
- **Blinking Blue:** Attempting to connect to Wi-Fi  
- **Solid Purple:** Failed to connect to Wi-Fi and switched to **setup mode**

---

## Wi-Fi Connection

1. Power on the controller.  
   The **right LED (Wi-Fi)** will begin **blinking blue**.

2. Wait several minutes.  
   If the controller cannot connect to a previously saved Wi-Fi network, it will switch to setup mode and the LED will turn **solid purple**.

3. On your phone or laptop, connect to the Wi-Fi network:
   - **SSID:** `navien_wifi`  
   - **Password:** `navien_wifi`

4. After connecting, a browser popup should appear prompting you to:
   - Select your home Wi-Fi network
   - Enter the Wi-Fi password

5. After credentials are submitted:
   - The unit will **restart automatically**
   - The right LED should change to **solid blue** once connected to your Wi-Fi

---

## Wiring Diagram

## Troubleshooting

| Problem | Solution |
|---|---|
| No browser popup after connecting to `navien_wifi` | “Forget” the `navien_wifi` network on your phone/tablet/laptop and connect again. |
| Purple light does not switch to blue after network credentials are entered | Unplug the device, wait a few seconds, and plug it back in. |

Additional practical checks:
- Ensure your home Wi-Fi is **2.4 GHz** if your router separates 2.4/5 GHz networks (many embedded Wi-Fi devices require 2.4 GHz).
- Keep the controller close to the router during initial setup.

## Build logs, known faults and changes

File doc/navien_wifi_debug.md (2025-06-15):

# Navien Wifi Lite

## Hardware
Navien Wifi Lite has two processors onboard: ARM STM32F4 and quite exotic MIXCHIP ECM3280-E wifi module, ironically also ARM based according to the [datasheet](DS0145EN_EMC3280_v2.3.pdf).

STM32F4 is wired to MAX485 RS485 transciever on one side and connected to the MIXCHIP ECM3280-E wifi module on the other. STM32F4 has all the code and logic of parsing the line level protocol over RS485 connection to Navien decies. MIXCHIP ECM3280-E appears to be taking the Wifi connectivity, registration and also communication with Navien app through AWS cloud.

Notice that the communication to cloud servers is over TLS/SSL, which makes packet capture quite difficult. It is not clear whether client cert validation is implemented or potential MiM interception is possible to substitute keys and extract payloads.

## SWD Interface

Diagram 1 shows the outline of key components as seen from the bottom of the PCB board inside Wifi Lite. The most interesing are the pins in the top left corner, which are wired to the onboard SWD interface of STM32F4, creating the possibility of debugging the firmware onboard.

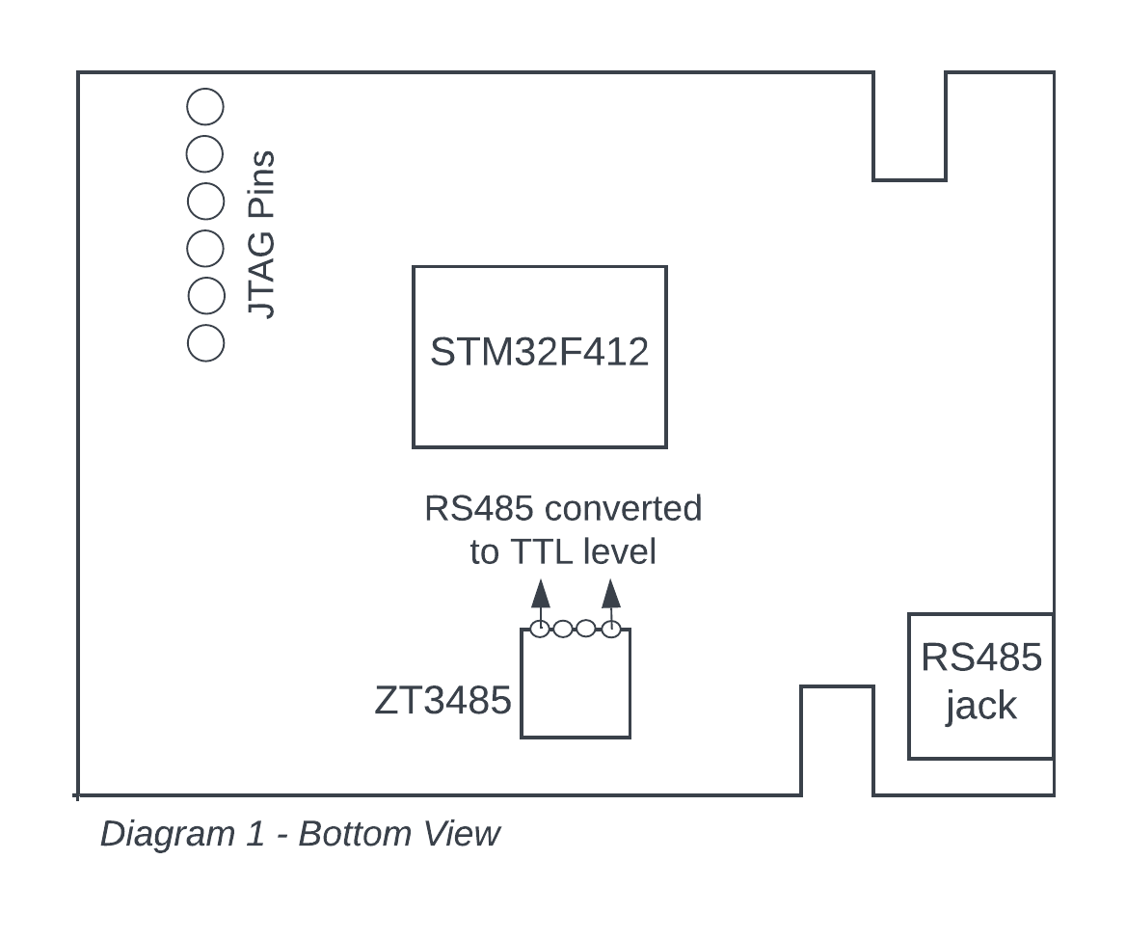
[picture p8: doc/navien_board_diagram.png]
Navien Board Diagram


STM32 devices can be debugged using either JTAG and SWD protocols. I did not find JTAG connectivity/port, but the SWD is present and confirmed to work.

The SWD setup for this board is as follows:

1. Install OpenOCD package
2. Connect ST-Link V2 Emulator Downloader Programmer to SWD pins as shown on the Diagram 2. For my experiments I've used a [cheap programmer from amazon](https://www.amazon.com/gp/product/B07SQV6VLZ) plugged into the USB port of the macbook.
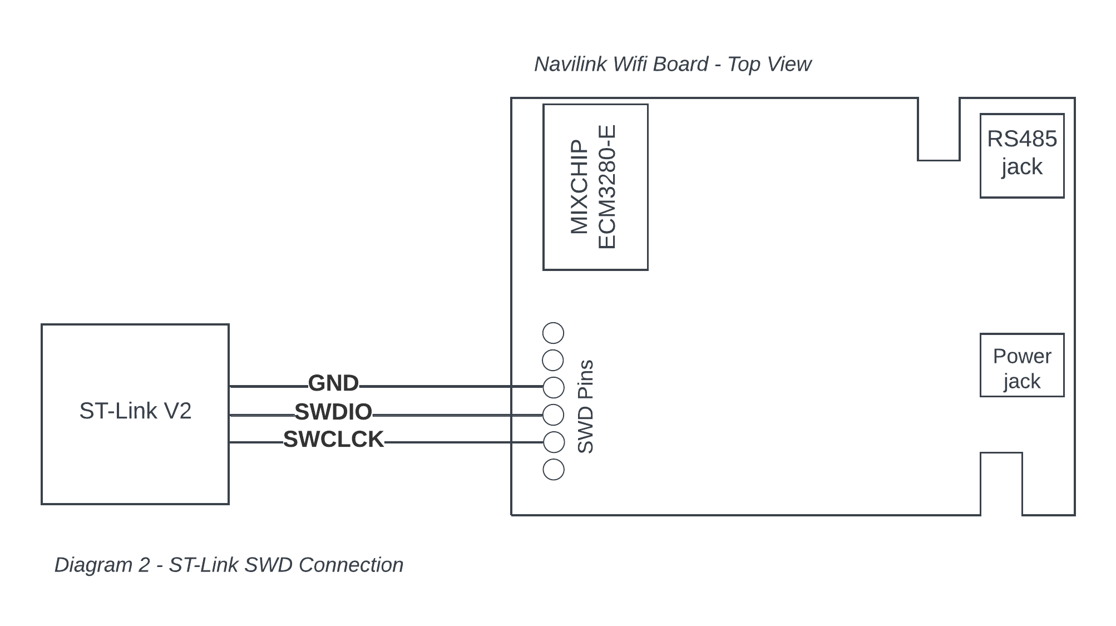
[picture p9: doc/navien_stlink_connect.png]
Navien ST-Link Connect


3. Start OpenOCD in the command shell with the following command (replace the path to openocd binary as necessary if it is not in your $PATH)
> openocd -f interface/stlink.cfg -f target/stm32f4x.cfg

4. Plug in the 12V power supply to the NaviLink

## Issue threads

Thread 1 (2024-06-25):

Any progress on the wire protocol / checksum?

itpeters, 2024-06-25:
Hi,

I stumbled across your work while trying to understand the Navien RS485 wire protocol. I have an ESP32 with TTL-RS485 converter connected to my Navien, and I've been watching some of the packets going back and forth.

From reading your work, it sounds like you believe the checksum to be CRC-8 of the entire packet (from the 0xF7 frame start through the end of the data), with the initial value dictated by the byte at offset 0x02 (either 0x62 or 0x4B) and (I'm assuming) polynomial 0x07.

I'm able to reproduce the first example you list:

```
>>> hex(crc.crc_poly(bytes.fromhex("F7 05 50 50 90 22 42 00 00 25 49 5C 5B 53 00 00 00 00 00 00 88 C2 00 20 02 00 00 00 21 03 99 08 00 02 00 00 00 00 00 00"), 8, poly=0x07, crc=0x62))
'0x87'
```

I'm not having the same success with your second example:

```
>>> hex(crc.crc_poly(bytes.fromhex("F7 05 50 50 90 22 42 00 00 25 14 5F 4C 4C 00 00 00 00 00 00 88 C2 00 20 02 00 00 00 21 03 9A 08 00 02 00 00 00 00 00 00"), 8, poly=0x07, crc=0x62))
'0xf3'
```

Your work showed this with a checksum of 0xD8.

I'm also not having any luck with the packets that I captured coming from my water heater. For example, I grabbed `F7 05 50 50 90 22 42 00 08 25 47 62 62 3E 00 00 00 00 00 00 08 9D 00 20 02 02 00 00 07 00 28 00 00 02 00 00 00 00 00 00 8A` but when I try to recreate the checksum I get something different:

```
>>> hex(crc.crc_poly(bytes.fromhex("F7 05 50 50 90 22 42 00 08 25 47 62 62 3E 00 00 00 00 00 00 08 9D 00 20 02 02 00 00 07 00 28 00 00 02 00 00 00 00 00 00"), 8, poly=0x07, crc=0x62))
'0x4d'
```

I was just curious if you see anything I'm doing wrong or misunderstanding, or if you have any more insights since you last put this up.

Thanks!

htumanyan, 2024-08-03:
Hello!
First of all, thank you so much for the attention and efforts! More of us try, sooner we get it reversed. I should admit I was a bit distracted for a few months, not making much progress. However, here is the reverse engineered CRC calculation code in case if it is helpful - this was on my list to document but never got a chance to - would very much appreciate any help.

undefined likely_crc_calc(byte *buffer,uint len,ushort seed)

{
  ushort uVar1;
  undefined *puVar2;
  byte *pbVar3;

  puVar2 = PTR_DAT_08031d7c;
  if ((int)len < 2) {
    *(undefined2 *)PTR_DAT_08031d7c = 0;
  }
  else {
    *(undefined2 *)PTR_DAT_08031d7c = 0xff;
    *(byte **)(puVar2 + 4) = buffer;
    while (pbVar3 = *(byte **)(puVar2 + 4), pbVar3 < buffer + ((len & 0xffff) - 1)) {
      uVar1 = *(short *)puVar2 << 1;
      *(ushort *)puVar2 = uVar1;
      if (0xff < uVar1) {
        *(ushort *)puVar2 = uVar1 & 0xff ^ seed;
      }
      *(byte **)(puVar2 + 8) = pbVar3;
      *(ushort *)puVar2 = *(ushort *)puVar2 ^ (ushort)*pbVar3;
      *(byte **)(puVar2 + 4) = pbVar3 + 1;
    }
  }
  return (char)*(undefined2 *)puVar2;
}

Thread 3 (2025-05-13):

2-wire protocol status

beren12, 2025-05-13:
Is there any chance you will work on the 2-wire protocol as well? I have a unit with that and would love to be able to change the set points via wifi instead of the remote, as well as have a timer to revert back to our preferred temp after a set time so others are less likely to get burned.

htumanyan, 2025-06-15:
Hello!
Thanks for asking and my apologies for taking forever to respond. I'd love to work on the two-wire protocol and it is in the plans. It is quite similar to the rs485 option as far as I can tell. I should admit, I don't know when I'll get to it though...

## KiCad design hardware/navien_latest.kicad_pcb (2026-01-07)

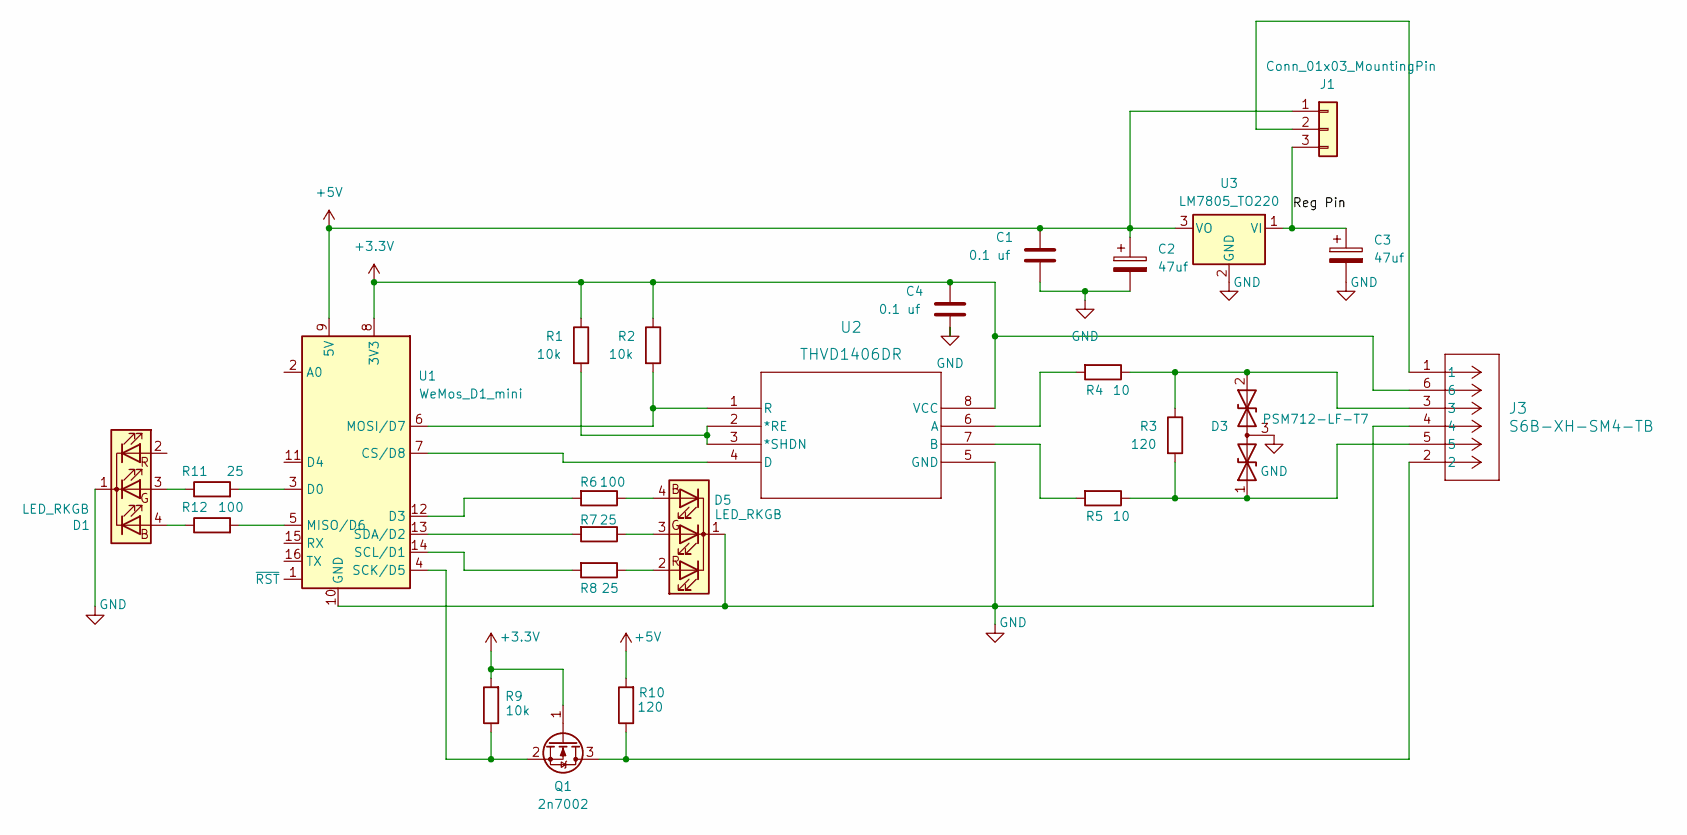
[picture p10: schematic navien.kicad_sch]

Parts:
C1, C4: 0.1 uf; C_0805_2012Metric_Pad1.18x1.45mm_HandSolder
C2, C3: 47uf; CP_EIA-3216-18_Kemet-A_Pad1.58x1.35mm_HandSolder
D1, D5: LED_RKGB; LED-ARRAY-SMD_4P-L1.6-W1.5-BL-FD
D3: PSM712-LF-T7; SOT-23
J1: Conn_01x03_MountingPin; PinHeader_1x03_P2.54mm_Vertical
J3: S6B-XH-SM4-TB; CONN_S6B-XH-SM4-TB_JST
Q1: 2n7002; SOT-23
R1, R2, R9: 10k; R_0805_2012Metric_Pad1.20x1.40mm_HandSolder
R3, R10: 120; R_0805_2012Metric_Pad1.20x1.40mm_HandSolder
R4, R5: 10; R_0805_2012Metric_Pad1.20x1.40mm_HandSolder
R6, R12: 100; R_0805_2012Metric_Pad1.20x1.40mm_HandSolder
R7, R8, R11: 25; R_0805_2012Metric_Pad1.20x1.40mm_HandSolder
U1: WeMos_D1_mini; WEMOS_D1_mini_light
U2: THVD1406DR; SOIC_D0008A_TEX
U3: LM7805_TO220; TO-220-3_Vertical

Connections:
+3.3V: C4.1, J3.6, Q1.1 (G), R1.1, R2.1, R9.2, U1.8 (3V3), U2.8 (VCC)
+5V: C1.1, C2.1, J1.1, R10.2, U1.9 (5V), U3.3 (VO)
/Reg Pin: C3.1, J1.3, U3.1 (VI)
GND: C1.2, C2.2, C3.2, C4.2, D1.1 (RA), D3.3 (common), D5.1 (Cathode), J3.4, U1.10 (GND), U2.5 (GND), U3.2 (GND)
unnamed: D1.3 (G), R11.1
unnamed: D1.4 (R), R12.1
unnamed: D3.1 (A1), J3.5, R3.2, R5.1
unnamed: D3.2 (A2), J3.3, R3.1, R4.1
unnamed: D5.2 (B), R8.1
unnamed: D5.3 (G), R7.1
unnamed: D5.4 (R), R6.1
unnamed: J1.2, J3.1
unnamed 12: R2.2, U1.6 (MOSI/D7), U2.1 (R); also elsewhere on the board
unnamed 13: U1.7 (CS/D8), U2.4 (D); also elsewhere on the board
unnamed: J3.2, Q1.3 (D), R10.1
unnamed: Q1.2 (S), R9.1, U1.4 (SCK/D5)
unnamed: R11.2, U1.3 (D0)
unnamed: R6.2, U1.12 (D3)
unnamed: R12.2, U1.5 (MISO/D6)
unnamed: R8.2, U1.14 (SCL/D1)
unnamed: R7.2, U1.13 (SDA/D2)
unnamed: R1.2, U2.2 (*RE), U2.3 (*SHDN)
unnamed: R4.2, U2.6 (A)
unnamed: R5.2, U2.7 (B)

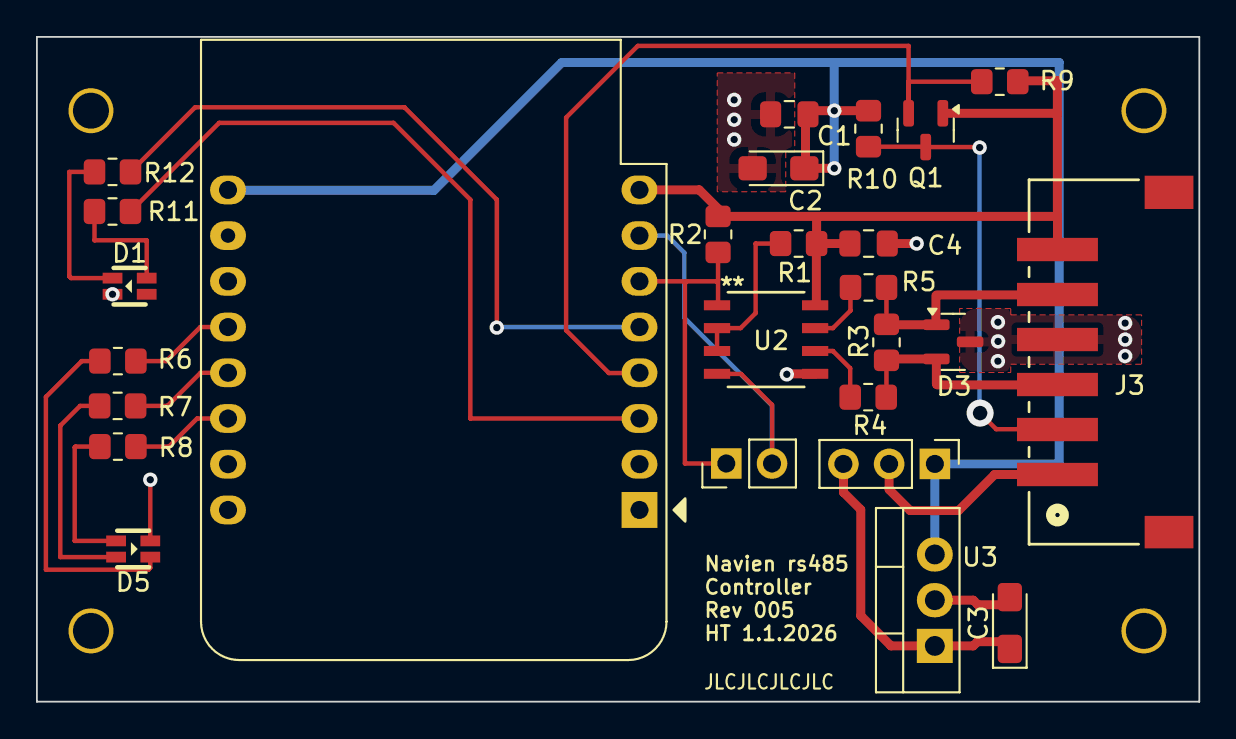
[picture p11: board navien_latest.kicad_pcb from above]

Board: 2 copper layers, 64.6 x 36.9 mm, 30 parts (0 on the bottom side), 24 nets.

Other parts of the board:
J2: Conn_01x02; PinHeader_1x02_P2.54mm_Vertical
REF1, REF2, REF3, REF4: MountingHole_2.2mm_M2

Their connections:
unnamed 12: J2.1; also elsewhere on the board
unnamed 13: J2.2; also elsewhere on the board

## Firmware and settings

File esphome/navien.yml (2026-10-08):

# Basic Config

substitutions:
  #   # https://esphome.io/guides/configuration-types.html#substitutions
  device_name: navien-heater # hostname & entity_id
  friendly_name: "Navien Gas Heater" # Displayed in HA frontend

esphome:
  # https://esphome.io/components/esphome
  name: ${device_name}

external_components:
  - source: 
      type: local
      path: components
    components: [navien]

esp8266: 
  board: d1_mini
  
wifi:
  ssid: !secret wifi_ssid
  password: !secret wifi_password
    
  # Enable fallback hotspot (captive portal) in case wifi connection fails
  ap:
    ssid: !secret ap_ssid
    password: !secret ap_password

captive_portal:

web_server:
  port: 80
  # https://esphome.io/components/web_server.html

logger:
#  level: VERBOSE #makes uart stream available in esphome logstream
  baud_rate: 0 #disable logging over uart

  hardware_uart: UART1 # redirect logs to UART1 GPIO2 to avoid conflicts
                       # with the MCU communication through the main hardware UART

  # https://esphome.io/components/logger
  level: INFO
  esp8266_store_log_strings_in_flash: false

api:

ota:
  platform: esphome


output:
  - platform: gpio
    pin: GPIO4  # D2 on esp8266
    id: uart_esp8266_d2

uart:
  tx_pin: GPIO15
  rx_pin: GPIO13
      
  baud_rate: 19200
  stop_bits: 1
  parity: none
  rx_buffer_size: 8192
  id: main_hw_uart


text_sensor:
  - platform: version
    name: $friendly_name ESPHome Version
    id: esphome_version
    hide_timestamp: True
  - platform: wifi_info
    ip_address:
      id: ip_address
      name: $friendly_name IP Address
    mac_address:
      name: $friendly_name Mac
      id: mac_address

sensor:
  - platform: uptime
    name: $friendly_name Uptime Sensor
  - platform: wifi_signal
    name: $friendly_name wifi signal
  - platform: navien
    name: $friendly_name Test sensor
    uart_id: main_hw_uart
    dhw_set_temperature:
      name: $friendly_name DHW Set Temp
      filters:
        - lambda: return x * (9.0/5.0) + 32.0;
      unit_of_measurement: "°F"
      device_class: temperature
      state_class: measurement
    inlet_temperature:
      name: $friendly_name Inlet Temp
      filters:
        - lambda: return x * (9.0/5.0) + 32.0;
      unit_of_measurement: "°F"
      device_class: temperature
      state_class: measurement
    outlet_temperature:
      name: $friendly_name Outlet Temp
      filters:
        - lambda: return x * (9.0/5.0) + 32.0;
      unit_of_measurement: "°F"
      device_class: temperature
      state_class: measurement
    sh_outlet_temperature:
      name: $friendly_name SH Outlet Temp
      filters:
        - lambda: return x * (9.0/5.0) + 32.0;
      unit_of_measurement: "°F"
      device_class: temperature
      state_class: measurement
    sh_return_temperature:
      name: $friendly_name SH Return Temp
      filters:
        - lambda: return x * (9.0/5.0) + 32.0;
      unit_of_measurement: "°F"
      device_class: temperature
      state_class: measurement
    water_flow:
      name: $friendly_name Water Flow
      filters:
        - lambda: return x / 3.785;
      unit_of_measurement: "gal/min"
      device_class: volume_flow_rate
      state_class: measurement
    water_utilization:  
      name: $friendly_name Water Capacity Utilization
      unit_of_measurement: "%"
    gas_total:
      name: $friendly_name Accumulated Gas Usage
      filters:
        - lambda: return x * 9131.0 / 25193.0 / 10.0;
      unit_of_measurement: "Therms"
      accuracy_decimals: 1
    gas_current:
      name: $friendly_name Current Gas Usage
      filters:
        - lambda: return x * 3.9680;
      unit_of_measurement: "BTU"
      accuracy_decimals: 1
    conn_status:
      name: $friendly_name Navien Connection Status
#    real_time: true           

binary_sensor:

switch:
  - platform: navien
    name: NavienOnOff


button:
  - platform: restart
    name: "Restart"
  - platform: navien
    name: NavienHotButton
    id: NavienHotButton


climate:
  - platform: navien
    id: navien_climate
    visual:
      min_temperature: 98F
      max_temperature: 110F
      temperature_step: '1°F'
    name: DHW Set Temperature

#output:
#  - platform: slow_pwm
##    pin: GPIO14
#    id: my_slow_pwm
#    period: 1s

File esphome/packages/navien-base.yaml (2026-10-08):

external_components:
  - source: github://htumanyan/esphome-navien@main
    components:
      - navien

time:
  - platform: homeassistant

web_server:
  version: 3

captive_portal:

api:

ota:
  - platform: esphome

logger:
  level: INFO

uart:
  id: main_hw_uart
  tx_pin: ${tx_pin}
  rx_pin: ${rx_pin}
  baud_rate: 19200
  stop_bits: 1
  parity: NONE
  rx_buffer_size: 8192

sensor:
  - platform: navien
    id: navien_main
    src: 0
    name: ${friendly_name} Metrics
    uart_id: main_hw_uart
    dhw_set_temperature:
      name: ${friendly_name} DHW Set Temp
      entity_category: diagnostic
      filters:
        - lambda: return x * (9.0/5.0) + 32.0;
      unit_of_measurement: °F
      device_class: temperature
      state_class: measurement
    inlet_temperature:
      name: ${friendly_name} Inlet Temp
      entity_category: diagnostic
      filters:
        - lambda: return x * (9.0/5.0) + 32.0;
      unit_of_measurement: °F
      device_class: temperature
      state_class: measurement
    outlet_temperature:
      name: ${friendly_name} Outlet Temp
      entity_category: diagnostic
      filters:
        - lambda: return x * (9.0/5.0) + 32.0;
      unit_of_measurement: °F
      device_class: temperature
      state_class: measurement
    water_flow:
      name: ${friendly_name} Water Flow
      entity_category: diagnostic
      filters:
        - lambda: return x / 3.785;
      unit_of_measurement: gal/min
      device_class: volume_flow_rate
      state_class: measurement
    water_utilization:
      name: ${friendly_name} Water Capacity Utilization
      entity_category: diagnostic
      unit_of_measurement: '%'
    heat_capacity:
      name: ${friendly_name} Heat Capacity
      entity_category: diagnostic
      unit_of_measurement: '%'
      accuracy_decimals: 1
    gas_total:
      id: gas_total_therms
      name: ${friendly_name} Accumulated Gas Usage
      entity_category: diagnostic
      filters:
        - lambda: return x * 9131.0 / 25193.0 / 10.0;
      unit_of_measurement: Therms
      accuracy_decimals: 1
    gas_current:
      id: gas_current_btu
      name: ${friendly_name} Current Gas Usage
      entity_category: diagnostic
      filters:
        - lambda: return x * 3.9680;
      unit_of_measurement: BTU
      accuracy_decimals: 1
    conn_status:
      name: ${friendly_name} Connection Status
      entity_category: diagnostic
    boiler_active:
      name: ${friendly_name} Boiler Active
      entity_category: diagnostic
    recirc_running:
      name: ${friendly_name} Recirculation Running
      entity_category: diagnostic
    recirc_mode:
      name: ${friendly_name} Recirculation Mode
      entity_category: diagnostic
    error_code:
      name: ${friendly_name} Error Code
      entity_category: diagnostic
    error_level:
      name: ${friendly_name} Error Level
      entity_category: diagnostic

  - platform: copy
    source_id: gas_total_therms
    name: ${friendly_name} Accumulated Gas Usage CCF
    entity_category: diagnostic
    unit_of_measurement: CCF
    device_class: gas
    state_class: total_increasing
    filters:
      - lambda: return x / 1.038;
    accuracy_decimals: 1
    disabled_by_default: true

  - platform: copy
    source_id: gas_current_btu
    name: ${friendly_name} Current Gas Usage kW
    entity_category: diagnostic
    unit_of_measurement: kW
    device_class: power
    state_class: measurement
    filters:
      - lambda: return x * 10.0 / 3412.0;
    accuracy_decimals: 1
    disabled_by_default: true

text_sensor:
  - platform: navien
    navien: navien_main
    name: ${friendly_name} Operating State
    entity_category: diagnostic
    operating_state: true
  - platform: navien
    navien: navien_main
    name: ${friendly_name} Heating Mode
    entity_category: diagnostic
    heating_mode: true

switch:
  - platform: navien
    navien: navien_main
    type: power
    name: ${friendly_name} Main Power
    entity_category: diagnostic
    id: main_power

button:
  - platform: navien
    name: ${friendly_name} Hot Button
  - platform: restart
    name: ${device_name} Restart
  - platform: safe_mode
    name: Flash Device (Safe Mode)
    icon: mdi:cellphone-arrow-down
    id: safe_mode_button

water_heater:
  - platform: navien
    navien: navien_main
    id: navien_water_heater
    visual:
      min_temperature: 98F
      max_temperature: 125F
      target_temperature_step: 1
    name: ${friendly_name}

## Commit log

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2024-08-27 Added the working code for checksum generation and validation along with test vectors derived from wire captures
2025-01-04 Added support for external secrets file Rename secrets.yaml sample into secrets.yaml and change XXXX to repsective ap name and password values
2025-02-03 Reworked the component structure for better alignment with esphome best practices Added Navien Switch for turning the heater on/off (tested to work with N240a)
    [navien.cpp, navien.yml]
2025-06-15 Fixed the compilation error due to incorrectly added button Added NavienOnOff switch for tracking the state of the device and also turning it on and off Added reporting of the water flow state
    [navien.cpp, navien.yml]
2025-06-15 Removed the unnecessray reference to custom button implementation Standard button does just fine
2025-06-24 Major refactoring to achieve greater flexibility: a. Created a new interface abstracting away the details of UART and modified the rest of the code to use that rather than the raw esphome UART API. b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
2025-06-24 Get 'upstream/refactor_separate_proto' compiling for me.
    Put the switch/button code under `USE_SWITCH`/`USE_BUTTON` in case the YAML config doesn't have a
    "switch:"/"button:" section. Move the pin write into the YAML config because my board doesn't have
    the pin.
    [navien.cpp, navien.yml, navien_link.cpp]
2025-06-25 Removed unnecessary parse_gas and parse_water that are now replaced with calls to on_gas and on_water in the implementation of NavienLinkVisitorI. Moved the code from parse_gas and parse_water to the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
    [navien_link.cpp]
2025-06-25 Fixed the incorrect position of water flow field and confirmed correct GPM reporting on the actual unit
2025-06-26 a. Fixed the bug in water flow calculation - was mistakenly treating the value as GPM while it was LPM b. Added the current gas consumption - it is reported in kkal/hr but shown as BTU in Navien. Imp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
    [navien.cpp, navien.yml]
2025-06-29 Added the water utilization (debugged to confirm proper functioning) Replaced the use of module-specific unit of m^3 with ESPHome standard
    [navien.cpp, navien.yml]
2025-06-29 Debugged and fixed the connection status reporting that was broken after refactoring. Moved the connection status into the Navien class from NavienLink. Previously I was hoping to move it to NavienLi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
    [navien.cpp, navien.yml, navien_link.cpp]
2025-06-29 Fixed the power on/off. Debugged and verified it is working Moved sensor updates into their own functions update_water_sensors and update_gas sensors so that we could call them either from the Pollin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
    [navien.cpp]
2025-06-30 Added connection status reporting Reversed, debugged and added support for "recirculation status" and measurement unit configuration
    [navien.cpp, navien.yml, navien_link.cpp]
2025-07-08 Added real time update of sensors upon receipt of packets if the configuration calls for real time updates (real_time: true)
2025-08-25 Split off the configuration into separate files to simplify building for various platforms.
    navien-wrd-hb.yml - for the option that has D5 pin connected to the hot button pin on Navien main board (hot button simulation)
    navien-ht-device.yml - for the custom device that was designed specifically for controlling Navien devices.
    navien-base.yml - base file re-used across all versions, contains common definitions
    navien.yml is still around but will be retired soon
2025-09-06 Updated the navien.yaml for the new structure of platofrm/board specification in the latest version of esphome
2025-09-06 Added Climate control that sets the target temperature and shows the target received from the Navien heater
2025-09-06 Fixed reading temp values from water packet (was missing proper conversion to temp units). Added support for modes - HEAT and OFF. Wired up the modes to the on/off state of the Navien unit. Turning o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
    [navien.cpp]
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2025-09-08 Removed unnecessary port manipulations. Added the thermostat (missed when thermostat support was developed)
    [navien.yml]
2025-09-19 Removed no longer necessary pull up pin directives that were inerfering with Atom boards
    [navien.yml]
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2025-09-26 Update CONF_GAS_TOTAL with device and state classes
    Allows sensor to be used in the energy dashboard
2025-10-09 Commented out the reverse engineered prototype to avoid compilation errors.
2025-10-09 Added the hardware KiCad project with schematic and PCB Added the PNG verison of schematic for easy preview
    [BOM-navien.csv, navien.kicad_pcb, navien.kicad_sch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]
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2025-11-29 Made LED lights come on/off based on Wi-Fi and RS-485 connection status
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2025-12-30 Temporary re-adddition of the soft rs485 button while figuring out a way to have both options
2026-01-07 doc: consolidate Navien 240 documentation (240A/240A2): add doc/240.md, update README, remove doc/240-a.md
    [BOM-navien.csv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]
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2026-01-11 Refactor(navien): extract enum-to-string helpers (op_state, heat_mode, device_type)
    [navien.kicad_pcb]
2026-01-12 Fixed the compilation error due to incorrect scoping of static functions in the previous commit. Removed unnecessary reference from atom-lite-esp32.yml Replaced static_cast with binary mask logic for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
    [navien-esphome-atom-lite-esp32.yml, navien.cpp]
2026-01-14 Refactor: Extract NavienLinkEsp as singleton for UART communication
    - Rename link_id to src across YAML and Python config files
    - Create NavienLinkEsp class to handle UART communication
    - NavienLinkEsp is now a Component with its own loop() for receiving data
    - NavienLinkEsp broadcasts received packets to all registered visitors
    - NavienBase now has NavienLinkEsp as a member via set_link() instead of inheritance
    - Singleton pattern in sensor.py ensures only one NavienLinkEsp instance
    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
2026-01-15 Phase 1 of refactoring to support multi-unit cascading setup. Modified the reception logic to decide on packet direction based on the direction field, modified the navien_link to pass along src id of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
2026-01-15 Restore text_sensor, switch components and YAML config from main branch. Added explicit navien IDs (navien_master, navien_slave) and parent references for multi-unit cascade support.
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2026-01-17 disabled parsing of control packets with the source other than 0xF as those are unknown at the moment (observed in cascade setup for 240A2 between navien units) and cause unnecessary errors.
    [navien_link.cpp]
2026-01-18 a. Thanks to collaboration with https://community.home-assistant.io/u/diffhome debugged and enabled support for Navien 240A2 in cascade configuration. b. Refactored sensor definitions- moved to a sep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
    [navien-esphome-atom-lite-esp32.yml]
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2026-01-19 Add support for scheduled recirculation
    This PR adds support for controlling when scheduled recirculation is active, which allows Home Assistant to replicate the weekly scheduling capability of the NaviLink app. It has been tested against 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
    It adds two new control packets `SCHEDULED_RECIRC_ON_CMD` and `SCHEDULED_RECIRC_OFF_CMD`. The first one tells the Navien unit that it can recirculate when it sees fit (and also triggers an immediate 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
2026-01-20 Fix Fahrenheit rounding issues
    [navien_link.cpp]
2026-01-21 Add support for m5Stack ATOM S3 Lite/Tail485
    Adds a configuration file for the ATOM S3 Lite with a Tail485, which uses a different pinout than the ATOM S3.
    Also adds info to `doc/240.md` about pin mapping between the 5-pin connector 1 and the NaviLink RJ45 cable.
2026-01-26 Use idf for atom-lite
    Also resolve an issue with the `/` character in the name of the power
    entity
    [navien-esphome-atom-lite-esp32.yml]
2026-01-26 Interactive build script
    - Add build.py for interactive firmware builds with persisted
    WiFi credentials and hardware selection
    - Add pyproject.toml for uv-based esphome dependency management
    - Copy firmware output to ./build/ for convenient access
    - Fix ESP32 Atom Lite config for ESPHome 2026.x:
    - Use ESP-IDF framework (now the default)
    - Replace fastled_clockless with esp32_rmt_led_strip
    - Fix switch name to remove reserved '/' character
    [navien-esphome-atom-lite-esp32.yml]
2026-01-31 Consolidate recirc sensors and fix mode detection
    - Merge scheduled_recirc_running and hotbutton_recirc_running into single recirc_running sensor (since they were mutually exclusive anyway)
    - Fix mode detection to check both bit 0 (internal) and bit 1 (external) for scheduled recirculation modes
    - Add RECIRC_OFF state to distinguish disabled from HotButton mode; renamed the other constants in the same enum to have the `RECIRC` prefix for consistency
    - Detect HotButton mode on/off from gas packet byte 21 bit 2
    - Expand recirc_mode sensor to show: Off, External HotButton, External Scheduled, or Internal Scheduled
    - Updated the automation to reflect the new recirc_running sensor name
    - Fixed a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
    [navien.cpp]
2026-02-09 fixed remote build through esphome dashboard. Added missing sensor include for D1 Mini builds
2026-02-17 Support configuration without switch or climate components
    Add USE_SWITCH/USE_CLIMATE guards around usage areas and minor
    refactoring to eliminate duplication.
2026-02-17 Rename various set_temp/target_temp fields to dhw_set_temp
    Including in config and config examples, though keep support for
    previous target_temp key name for backwards compatibility.
    This will help disambiguate what is being referred to when support for
    space heating set temp is added.
2026-02-17 Add support for space heating set temperature
    The value comes from gas packet field index 13, previously known as
    panel_version_hi.
    Confirmed by observing NFC-250/175H unit.
2026-02-19 Move receive to loop to fix RS-485 timing
    Previously, with the removal of NavienLinkEsp, the receive() call was moved to update() which only runs once per polling interval (typically once/sec).
    This caused critical communication issues:
    1. Checksum errors: UART bytes accumulated between polls, causing the parser to read across packet boundaries and misalign headers/bodies:
    ```
    [08:56:33.193][E][navien.link:101]: SRC:0x50 Status Packet checksum error: 0x45 (calc) != 0x01 (recv), seed=0x4B
    [08:56:33.193][I][navien.link:305]: F7 05 50 50 90 22 06 3F 00 EC 01 00 00 00 00 06 00 F7 00 4E 00 00 01 C9 00 00 00 00 00 00 00 F7
    [08:56:33.203][I][navien.link:311]: 05 50 0F 90 2A 4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
    [navien.cpp]
2026-02-21 Fix error handling and src
    Changes where on_error() is called from so it's only called for actual errors, not whenever there's no command to send (fix migrated from #41 since this PR doesn't work well without it).
    Also added a guard in loop() to only call receive() if the Navien object is the primary instance, to prevent extra receive() calls in a cascaded setup.
    [navien.cpp, navien_link.cpp]
2026-02-21 Restore sending of `NAVILINK_PRESENT` packets
    This PR restores the sending of `NAVILINK_PRESENT` packets, which are needed in scheduled mode in order to tell an NPE-A2 device that it should let their recirculation schedule be controlled by the E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
2026-02-22 Handle configuration without all sensors defined in on_error
    And reset state for all currently sensors.
    [navien.cpp]
2026-02-22 Add decoding and sensors for outdoor temperature
    Gas packet byte 19 observed on NCB and NFC models.
2026-03-03 Fix buffer overflow in print_buffer() in navien_link.cpp and navien.cpp
    snprintf() was called with sizeof(hex_buffer) as the size limit, but
    the destination pointer was offset into the buffer. This could write
    past the end of the buffer on the last byte(s) of a 32-byte row.
    Fix by passing the remaining capacity (sizeof(hex_buffer) - offset)
    instead of the full buffer size.
    [navien.cpp, navien_link.cpp]
2026-03-19 Fix compatibility with ESPHome 2026.3.0
    ESPHome 2026.3.0 packed EntityBase setters (`set_icon`, `set_device_class`,
    etc.) into `configure_entity_()`, which is driven by the config dict
    rather than individual codegen calls (#14564). It also replaced
    `esphome::optional` with `std::optional` for C++17 compliance.
    Move sensor and binary_sensor icons into schema parameters so they flow
    through `configure_entity_()` automatically. For text_sensor, inject the
    default icon via a config validator (the shared schema makes per-type
    defaults impractical otherwise).
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2026-03-29 Fix cascade status routing by source address
    [navien.cpp, navien_link.cpp]
2026-04-09 Add Water Heater implementation for use with esphome >= 2026.2.0
    Fixes #35
    [navien.cpp]
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2026-04-10 Add decoding and sensors for error code and level
    [navien.cpp]
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2026-10-06 Add NHB-H device type and heating mode, show raw values for unknowns (#89)
    * Show raw code for unrecognized device types
    Device Type now reads "Unknown (N)" instead of "unknown" when the unit
    reports a code missing from DEVICE_TYPE, so unsupported models (e.g.
    NHB-H) can be identified and added.
    * Add NHB-H device type (code 16)
    An NHB-110H reports device type 16, one past CAS_NVW. Map it to
    "NHB-H" instead of falling through to "Unknown (16)".
    * Show raw value for unrecognized heating modes
    Heating Mode now reads "Unknown (0xNN)" instead of "unknow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
    [navien.cpp]
2026-10-06 Add LOLIN C3 Mini ESPHome configurations (#88)
    Add standalone and dashboard-importable configurations for the
    LOLIN/WEMOS C3 Mini.
    - Configure the ESP32-C3 with 4 MB flash and ESP-IDF.
    - Use GPIO21/GPIO20 for UART and GPIO7 for the onboard WS2812 status LED.
    - Document both setup paths and the RS-485 electrical safety boundary.
    - Keep the previously submitted Navien platform auto-load fix out of this change.
    Validated with ESPHome 2026.8.2 and ESP-IDF 5.5.5.
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2026-10-08 Add Waveshare ESP32-S3-RS485-CAN board support (#79)
    * Add Waveshare ESP32-S3-RS485-CAN board support
    - New board config using the confirmed RS485 pinout for this board
    (TX=GPIO17, RX=GPIO18, flow_control_pin=GPIO21), plus the
    board_build.flash_mode: dio workaround for a known post-flash boot
    loop on this board.
    - Adds device_class and state_class to the temperature and water_flow
    sensors so Home Assistant can auto-convert display units per its own
    configured unit system, no firmware change needed to switch between
    metric and imperial display.
    * Fix invalid GPM unit for volume_flow_rate device class
    HA only accepts gal/min (not GPM) as a valid unit string for the
    volume_flow_r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
2026-10-08 Auto-load binary_sensor for navien component (#86)
    navien.h unconditionally includes esphome/components/binary_sensor/binary_sensor.h,
    but the component never declared a dependency on it. When a config used the navien
    sensor platform without a top-level binary_sensor block, ESPHome would not copy the
    core binary_sensor component into the build tree, causing a compile failure:
    'esphome/components/binary_sensor/binary_sensor.h: No such file or directory'.
    Add AUTO_LOAD for binary_sensor (plus text_sensor and button, which navien.h and
    the platforms also reference) so the required core components are always bundled.
2026-10-08 fix(config): remove legacy sensor keys and normalize naming
    Fixes #73.
    Remove obsolete Navien YAML keys that were no longer valid in the current schema and normalize the device metadata to the standard ESPHome substitutions used across the repo. This resolves the config drift that caused the compile failure without changing the underlying protocol behavior.
    Validated:
    - esphome compile esphome/navien.yml
    - esphome compile esphome/navien-ht-device.yml
    [navien.yml]
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2026-11-12 Prevent receive-buffer overflow on malformed frames (#98)
